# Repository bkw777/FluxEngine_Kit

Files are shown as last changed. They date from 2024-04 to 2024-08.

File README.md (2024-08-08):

# FluxEngine Kit

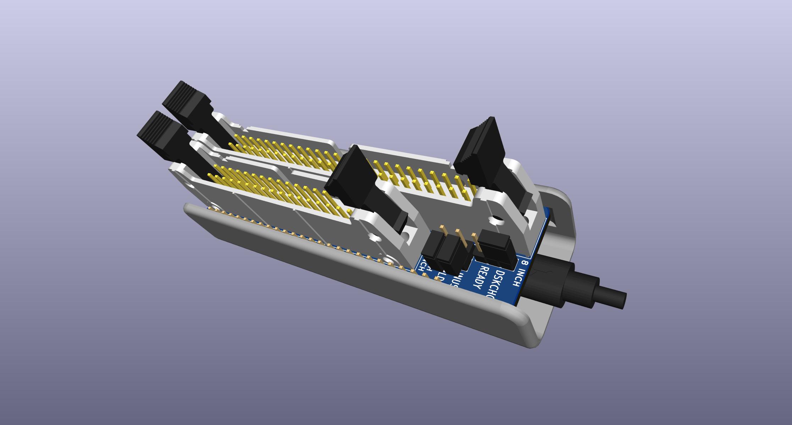
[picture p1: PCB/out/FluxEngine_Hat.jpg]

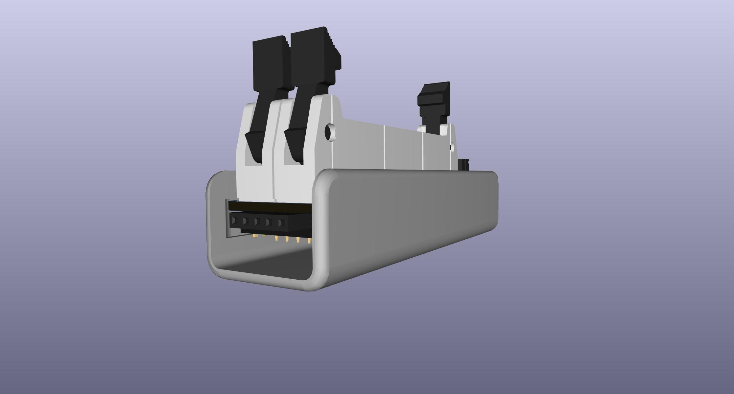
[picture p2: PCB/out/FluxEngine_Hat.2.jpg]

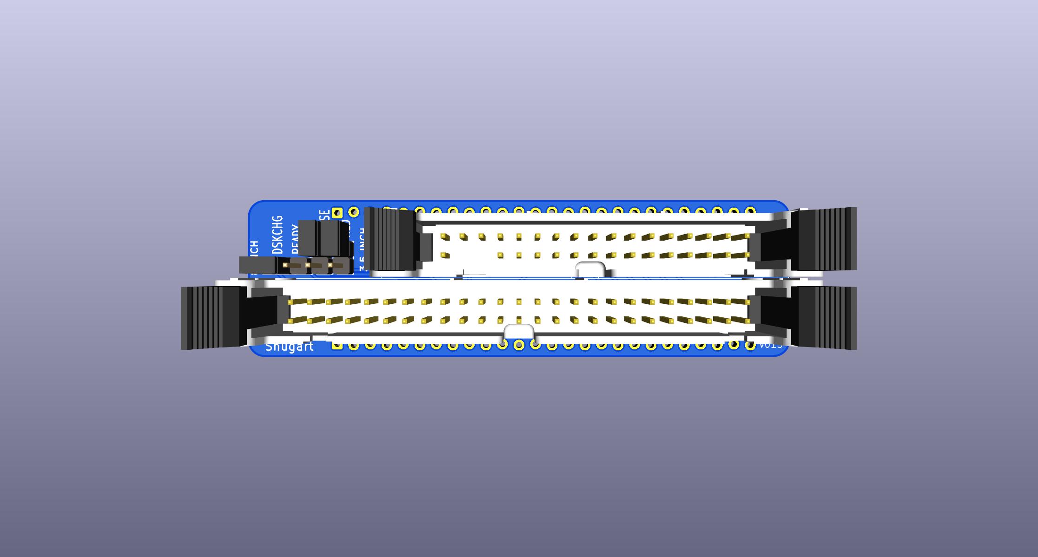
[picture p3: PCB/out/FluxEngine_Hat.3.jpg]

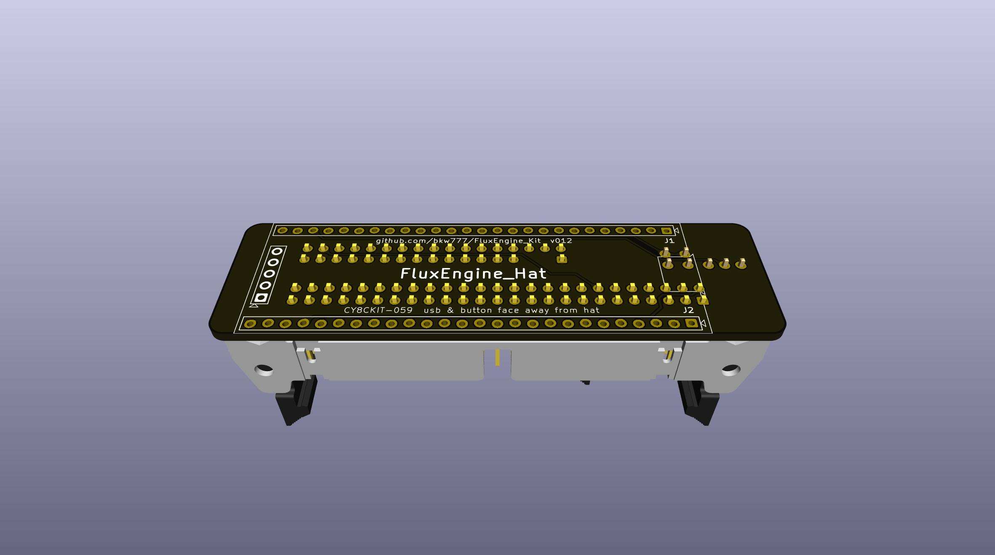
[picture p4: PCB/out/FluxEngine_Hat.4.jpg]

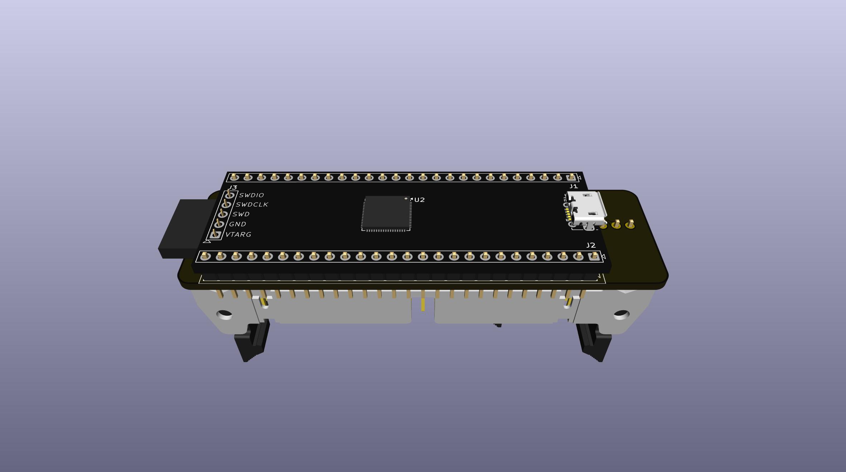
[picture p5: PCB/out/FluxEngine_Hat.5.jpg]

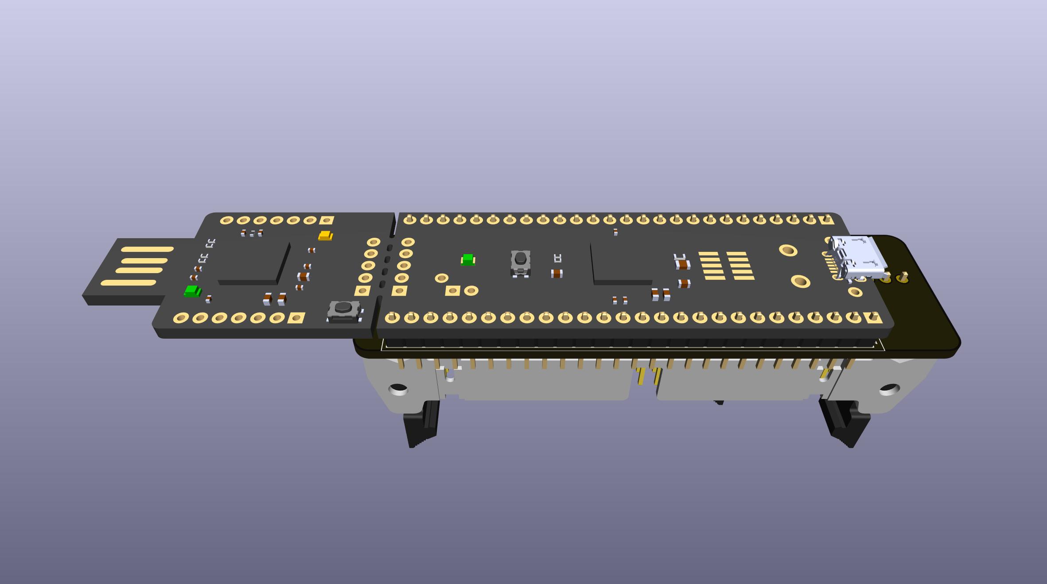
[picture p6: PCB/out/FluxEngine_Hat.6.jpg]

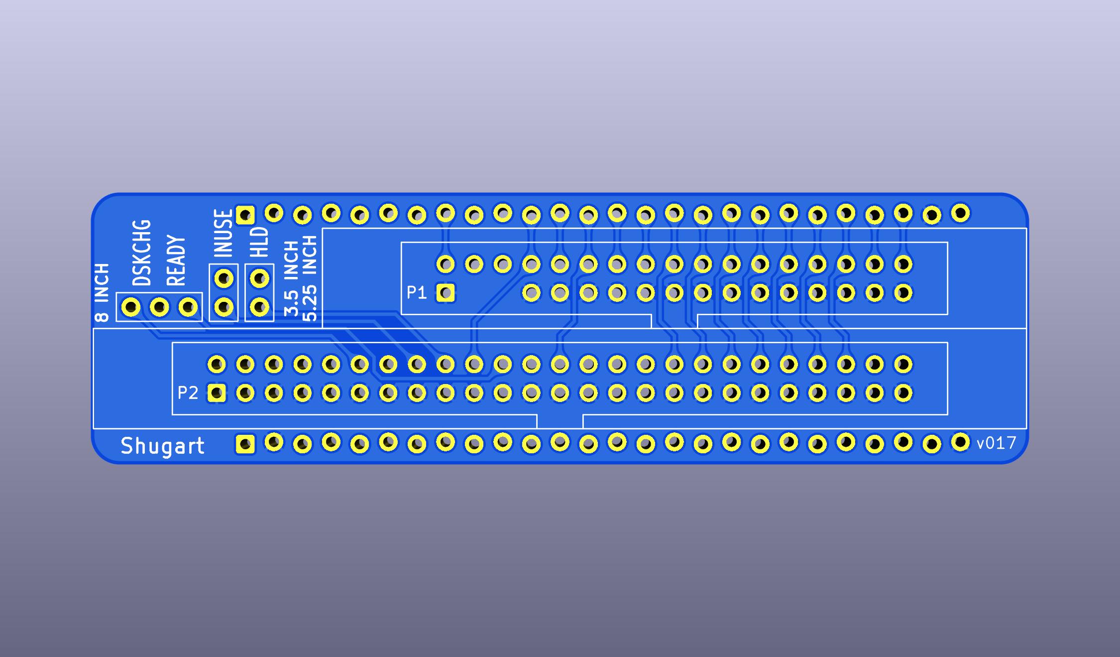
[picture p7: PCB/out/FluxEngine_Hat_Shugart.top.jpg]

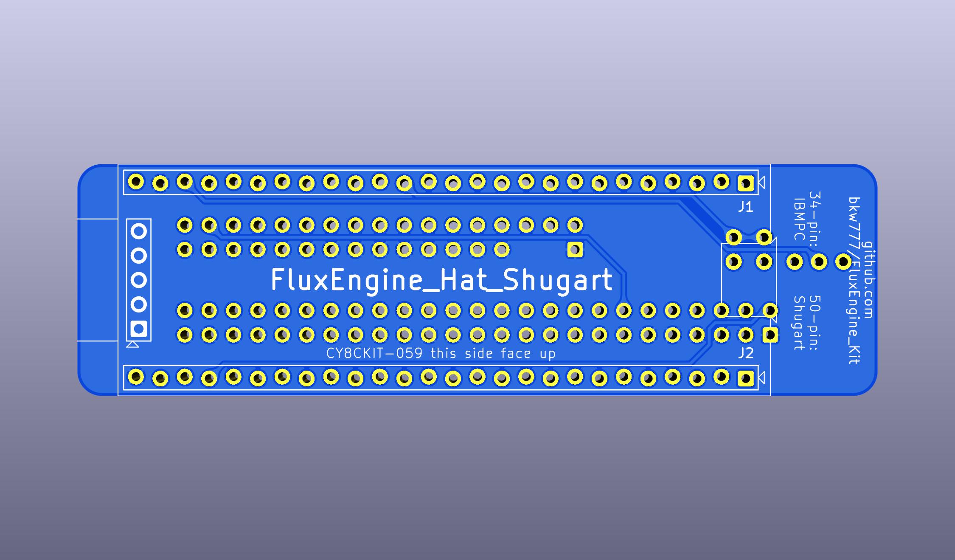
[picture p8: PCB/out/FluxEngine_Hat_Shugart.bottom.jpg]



THESE PCBs ARE NOT TESTED YET

This is a set of adapter PCBs and printable snap covers to build a nice version of [FluxEngine](http://cowlark.com/fluxengine/)

I am not the creator of FluxEngine itself, just this adapter PCB and printable cover.

Most people probably do not need any of these pcbs. They are really just to provide convenient support for 8-inch drives.

If you're not trying to use 8-inch drives, then you don't need any adapter pcb like this.  
The FluxEngine pinout is already designed so that you can just solder a 34-pin connector directly to the CY8CKIT-059 fpga board.  
You can use the BOM link below and delete everything but the CY8CKIT-059 and the 34-pin connector, no pcb, no printed cover.

The PCBs are designed to NOT need to be soldered. You can connect and remove and reconnect the fpga board without, and without needing to install actual sockets.
You CAN still solder them normally if you want to make a permanent FluxEngine, you just don't have to.

It means you can swap the same fpga board between all 3 (so far) hat versions, and then still also use the fpga board on a breadboard when not using it for FluxEngine.

What you do is solder pins to the bottom of the fpga board the same as if you were using it on a breadboard. And that's it. You can install actual matching sockets on the hat PCBs, but you don't have to. The zig/zag pin row layout on the hat PCBs makes solid electrical contact with the pins without needing a socket.

For the sake of the solderless pin connections, I suggest getting the PCBs made with ENIG finish (gold plating on the copper).  
It's not required though. Honestly the way the square edges of the pins bite into the via walls it probably will never make any difference.  
Some fabricators charge more than others for ENIG. OSHPark is always ENIG no matter what, so that's easy. But between PCBWAY, JLCPCB, and Elecrow, Elecrow charges a lot less for ENIG.

The cover (both styles) prints easily with any basic home FDM printer with PLA. I actually use a $150 Monoprice from 6 years ago.  

But also these days most of the PCB shops also offer 3d printing, so you can get the pcb and the cover printed professionally in sintered nylon from the same place on the same order.  
The link below is to PCBWAY only because it's the most convenient where you can just click "buy" on something already pre-loaded, but actually if you go to Elecrow and just upload the gerber zip and cover stl, it's just as simple and significantly cheaper, especially with ENIG.

## Parts
[BOM from DigiKey](https://www.digikey.com/short/q5zh79n9)  
[PCB and Cover from PCBWAY](https://www.pcbway.com/project/shareproject/FluxEngine_Hat_e3000eb5.html)

Power supply and cables:  
[Molex power supply](https://amazon.com/dp/B000MGG6SC)  
[Molex to Berg splitter](https://amazon.com/dp/B0002J1KW6)  
[Molex to Molex splitter](https://amazon.com/dp/B00007JO36)  
[Floppy drive cable](https://amazon.com/dp/B07KDJTMGP)  

## Cover

There are a few versions of printable cover in releases, all generated from the same OpenSCAD source.  
Two main styles, simple and fancy, in three sizes each, lowprofile, default, and one for if you have full pin sockets installed.  

## Configuration

The jumpers only affect the 50-pin connector for 8-inch drives.  

### DSKCHG / READY
Connects either the /DSKCHG or /READY output from the drive to the /DSKCHG input on the FluxEngine.  

Install jumper on DSKCHG by default.

### INUSE
Connects the /MOTB (motor-B-on) output from the FluxEngine to the /IN-USE aka /DOOR-LOCK input on the drive.

Not connected by default, but stow a jumper on one pin.

### HLD
Connects the /MOTB (motor-B-on) output from the FluxEngine to the /HEAD-LOAD input on the drive.

Not connected by default, but stow a jumper on one pin.

INUSE/HLD is not either-or. You may need either, or neither, or both.

# Control Data / Magnetic Peripherals / Honeywell 8-inch drives

Some CDC 8-inch drives like the 9404 and 9406-4 lines are Shugart compatible, and so for those just use the SA850 hat like any other Shugart interface drive.

Others have compatible signals but different pinouts.

The two tables below come from two CDC manuals covering many similar drive models spanning several years.  
Left: [CDC FDD FSM ('79)](PCB/datasheets/CDC_77834769_Y__FDD_FSM.pdf)  
Right: [CDC 9406 FSM ('82)](PCB/datasheets/CDC_77614903_AM__9406_FSM.pdf)  

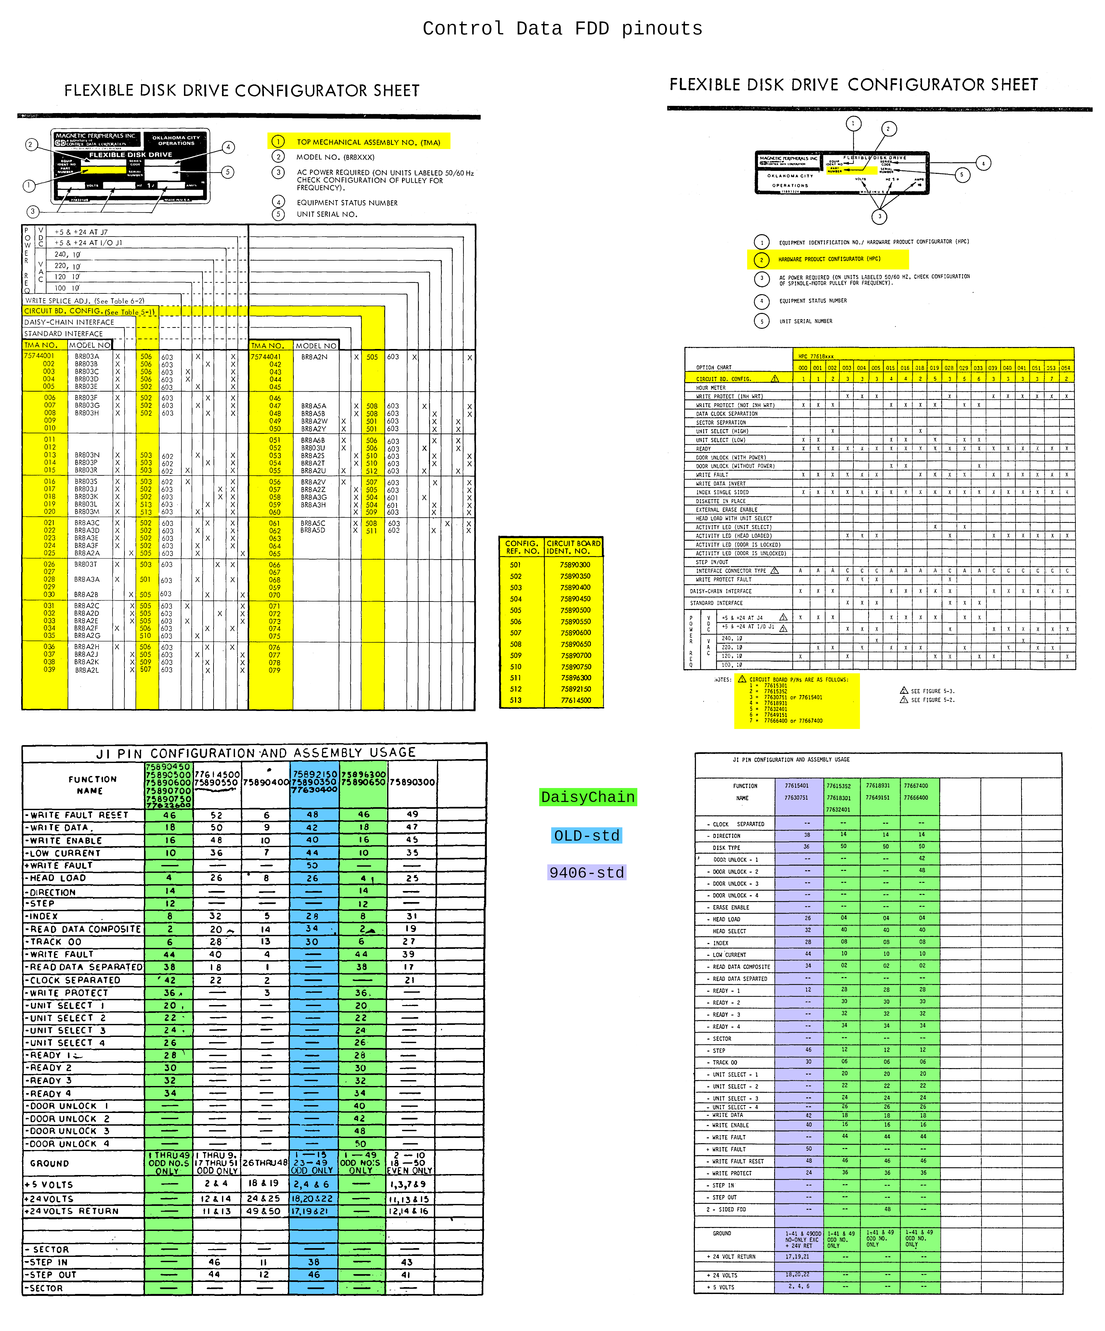
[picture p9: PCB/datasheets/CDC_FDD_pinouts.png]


There are two hats that cover the most common CDC pinouts.

The "CDC-daisychain" hat supports all the green highlighted models.

The "CDC-standard" hat supports the blue and purple highlighted models.

"standard" is mis-named because what CDC called "standard interface" in the manuals was several different pinouts and interfaces.  
But of the several pinouts they called "standard", 2 are actually the same except for STEP+DIRECTION vs STEP_IN/STEP_OUT, and most models that don't have the "daisychain" interface seem to have one of these two versions of "standard".  
So the '''CDC-standard''' hat includes logic to optionally convert the STEP+DIRECTION signals from the FluxEngine to STEP_IN/STEP_OUT signals for the drive if needed.

For drives that need STEP_IN/STEP_OUT, install the 2 jumpers on STEP_IN and STEP_OUT. (earlier and less common drives)  
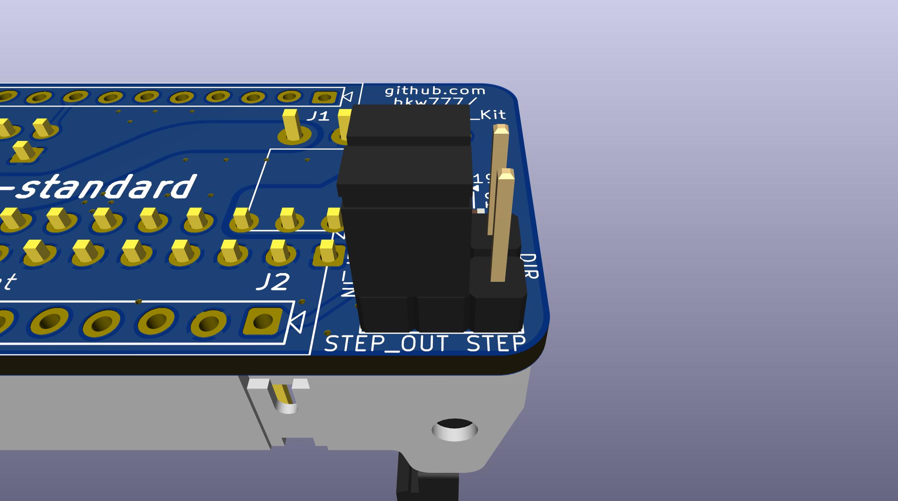
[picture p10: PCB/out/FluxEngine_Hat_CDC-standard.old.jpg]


For drives that need STEP+DIRECTION, install the 2 jumpers on DIR and STEP. (default, later and more common drives)  
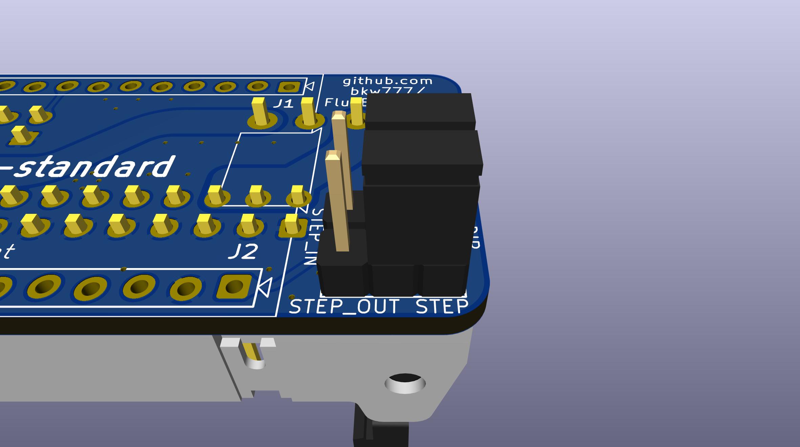
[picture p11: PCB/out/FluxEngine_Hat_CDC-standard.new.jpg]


If you don't need the STEP_IN/STEP_OUT option, you don't need to populate C1 or U1 or the jumper pins. Just use solder or wire in place of the STEP & DIR jumpers and leave the U1 and C1 footprints empty.  
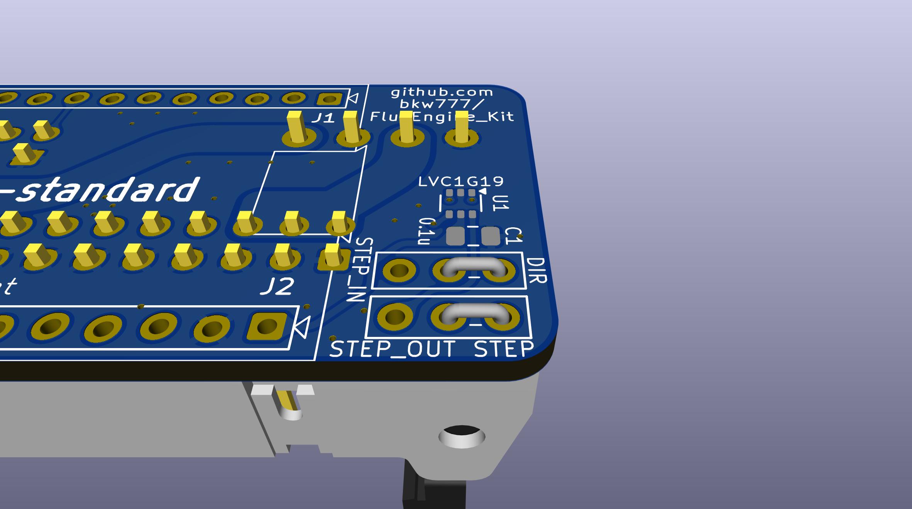
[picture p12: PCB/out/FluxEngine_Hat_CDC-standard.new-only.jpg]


NONE OF THESE ARE TESTED YET  


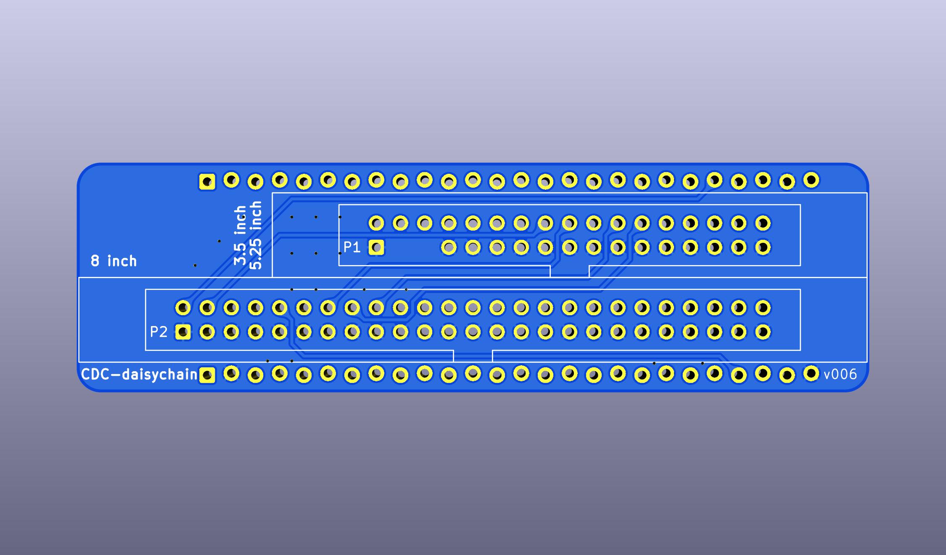
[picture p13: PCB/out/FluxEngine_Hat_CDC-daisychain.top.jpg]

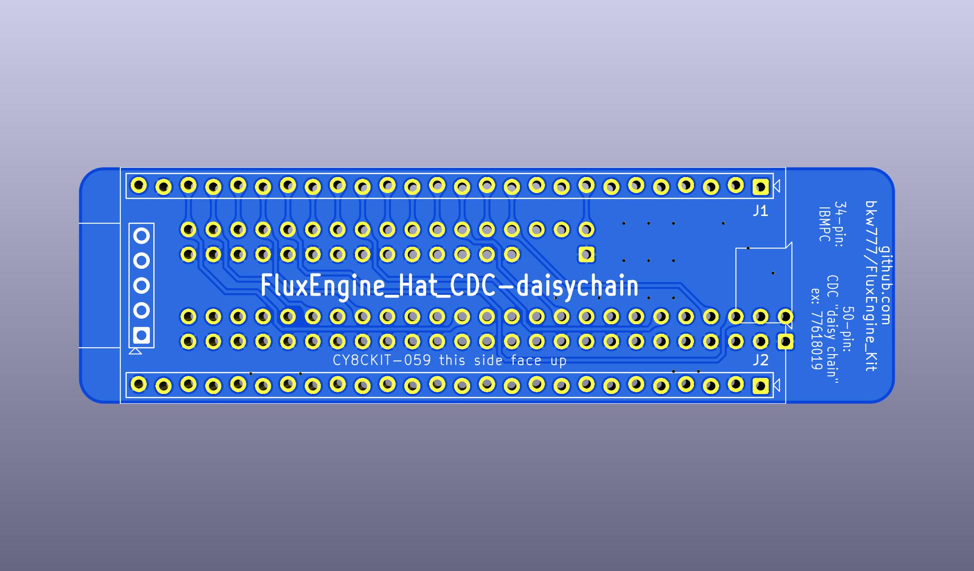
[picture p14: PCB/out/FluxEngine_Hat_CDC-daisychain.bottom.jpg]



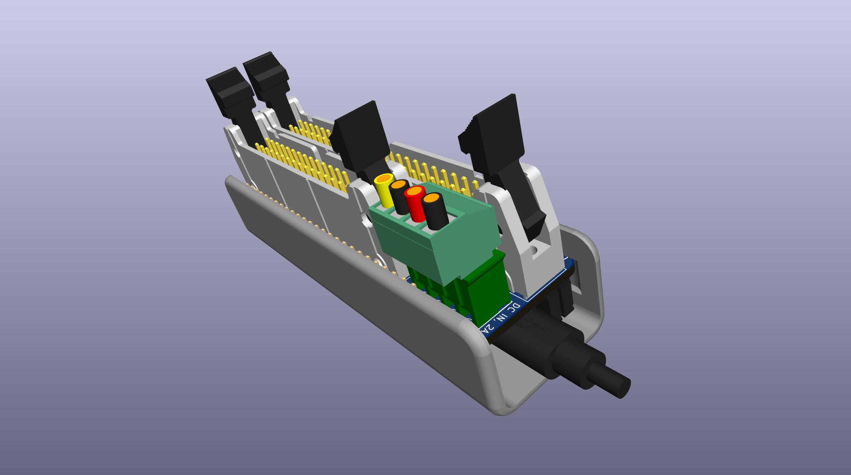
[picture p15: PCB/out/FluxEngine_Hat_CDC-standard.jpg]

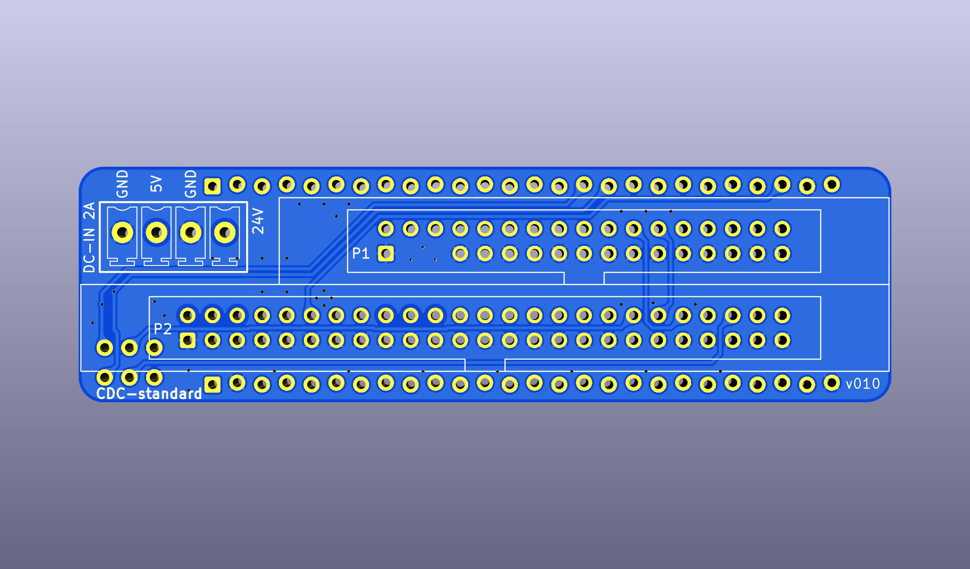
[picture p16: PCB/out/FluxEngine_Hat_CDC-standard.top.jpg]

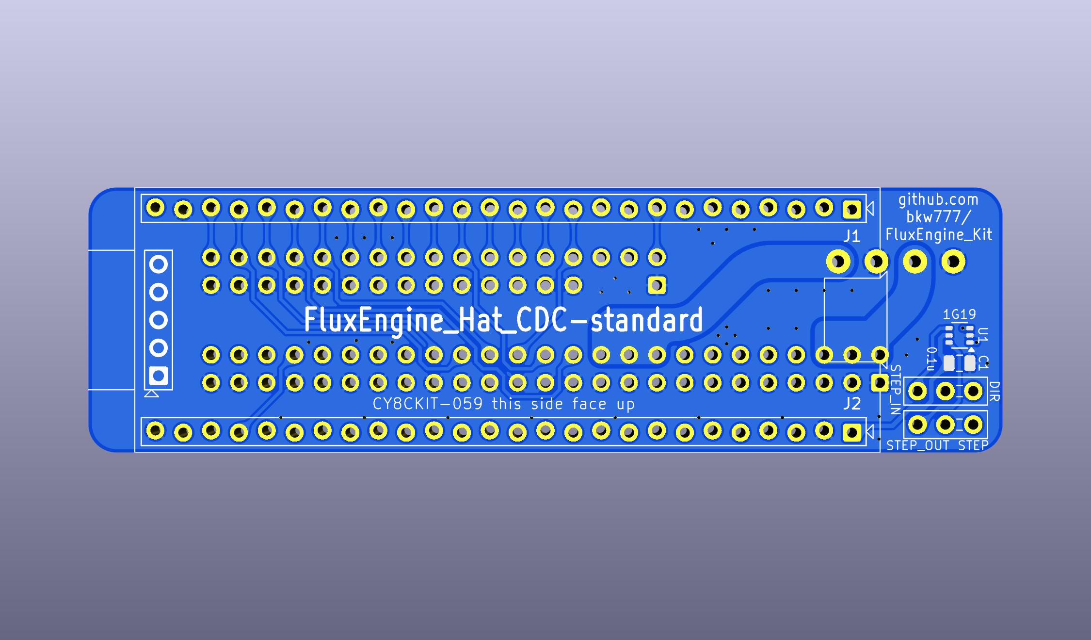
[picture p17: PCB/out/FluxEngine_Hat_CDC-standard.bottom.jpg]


CDC-daisychain BOM:  
Standard BOM, delete the jumpers.  

CDC-standard BOM:  
Standard BOM, add these:  
[screw terminal header](https://www.digikey.com/en/products/detail/phoenix-contact/5452094/5186805)  
[screw terminal plug](https://www.digikey.com/en/products/detail/phoenix-contact/5452178/5187210)  
[74LVC1G19 1to2 decoder](https://www.digikey.com/en/products/detail/nexperia-usa-inc/74LVC1G19GW-125/1231453)  
[C 0.1u 0805](https://www.digikey.com/en/products/detail/kyocera-avx/KGM21NR71E104KT/1116281)  

### More 8-inch info

The AC & DC power connectors were the same on many drives.  
These are the cable-side connector housings and female pins needed to make proper cables to connect to most drives.

3-pin AC power:  
Housing: [AMP/TE 1-480700-0](https://www.digikey.com/en/products/detail/te-connectivity-amp-connectors/1-480700-0/29339)  
Female pins: [AMP/TE 350536-1](https://www.digikey.com/en/products/detail/te-connectivity-amp-connectors/350536-1/287712)

6-pin DC power:  
Housing: [AMP/TE 1-480270-0](https://www.digikey.com/en/products/detail/te-connectivity-amp-connectors/1-480270-0/15668)  
Female pins: [AMP/TE 61117-1](https://www.digikey.com/en/products/detail/te-connectivity-amp-connectors/61117-1/290254)

They do make dual-output power supplies that output both 5v and 24v, but it's actually cheaper to buy seperate supplies.  
A typical drive draws about 1.0A-1.5A from either DC rail while working.  
Here are a couple of supplies just for convenience & reference:  
[5V 3A Meanwell](https://www.digikey.com/en/products/detail/mean-well-usa-inc/RS-15-5/7706168)  
[24V 3.2A Meanwell](https://www.digikey.com/en/products/detail/mean-well-usa-inc/RS-15-5/7706168)

### Probably CDC-specific

The CDC manuals do not say this anywhere, but many drives have a variant of the 50-pin IDC header with two polarity key slots instead of one in the center. The drawings and actual part numbers in the service manuals only show the normal single-notch type.  
A normal IDC plug with polarity key does not fit. Non-polarized plugs fit, but here are a couple of fully polarity-keyed female IDC plugs that fit:  
[Omron XG4M-5031-T](https://www.digikey.com/en/products/detail/omron-electronics-inc-emc-div/XG4M-5031-T/1829402)  
[Hirose HIF3BA-50D-2.54R](https://www.digikey.com/en/products/detail/hirose-electric-co-ltd/HIF3BA-50D-2-54R-63/12758574)

Connector housing & contacts to fit the 7-pin power connection on CDC drives.  
The pins are .156" pitch, and have a .031"x.062" flat blade shape not square.  
The pin and housing series is called "AMPMODU MOD I", and you want specifically the high pressure version of the receptacles for power vs merely signal usage.  
Only the 4 middle pins are connected, so you could uses as little as a 5-position housing, but ideally you still want a housing with all 7 (or more) positions, and receptacles installed for all 6 pins, because the extra 2 pins provide both strain relief and extra retention friction.  
[TE 87159-7 - AMPMODU MOD I receptacle housing, 7-pin, non-locking, keyed](https://mou.sr/4bhcBrf) (cut the key bumps off)  
[TE 102100-2 - AMPMODU MOD I pin receptacle, non-locking high-pressure 18-22awg gold-30uin](https://mou.sr/44tt5K6) (need 6)  
[TE 87116-2 - AMPMODU MOD I keying plug](https://us.rs-online.com/product/te-connectivity/87116-2/70287356/) (need 1)

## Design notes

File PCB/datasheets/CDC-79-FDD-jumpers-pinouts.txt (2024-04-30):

CDC FDD config jumpers for 8-inch models up to '79
from CDC_77834769_Y__FDD_FSM.pdf

Aside from looking at the schematic, trying to decode the config jumper table to
determine if there are config jumpers that correspond to STEP+DIR vs STEP_IN/STEP_OUT

Pinout groups (J1 config columns) 1 and 5 are the same except
group 5 adds DOOR_UNLOCK1-4 inputs and removes the SEP_DATA output.

Groups 2,3,4,6 are all the ones with STEP_IN/STEP_OUT at all, regardless of pinout.

Group 4 is the only one with all pins the the same as "ALT1"
(pinout group 1 from the later 9406 manual)
except for STEP_IN/STEP_OUT vs STEP+DIRECTION.

Some config changes involve installing different components
in a given footprint which changes functionality/behavior,
not just jumpers, but none of those are different for column 4.
(all the same ICs and values, at least in the stepper area)

Re-write of the jumper table with the related configs grouped together
-----------------------------------------------------------------------------
assembly  J1 cfg
number    column   installed W# locations
-----------------------------------------------------------------------------
                :  1 2 3 4 5 6 7 8 9 10 11 12 13 14 15 16 17 18 19 20 21 22 23 24 25 26 27 28 29 30 31 32 33 34 35 36 37 38
--------------------------------------------------------------------------------------------------------------------------
75890450    1   :    2   4     7              13    15 16             21 22       25    27    29    31                37
75890500    1   :    2   4     7           12 13 14 15                21 22       25    27    29    31             36 37
75890600    1   :    2   4     7              13 14 15                21 22    24       27    29    31                37
75890700    1   :    2     5   7              13 14 15             20       23 24       27    29    31             36 37
75890750    1   :    2   4     7              13 14 15                21 22       25    27    29    31             36 37
77622600    1   :    2   4     7              13 14 15    17          21 22       25    27    29    31             36 37
                :
75890650    5   :    2   4     7 8            13 14 15       18       21 22       25    27    29 31             35    37
75896300    5   :    2   4     7 8            13 14 15       18       21 22       25    27    29 31             35    37 
77624750(1) 5   :    2   4     7 8            13 14 15       18       21 22       25    27    29 31             35    37

75890550    2   :    2     5 6          11    13    15                21 22    24       27    29 31                   37
77614500    2   :    2     5 6          11    13    15                21 22    24       27    29 31                   37
75890300(2) 6   :    2     5 6          11    13    15                21 22    24       27    29 31                   37

75890400    3   :    2   4     7        11    13    15 16             21 22       25    27    29 31                   37

75890350    4   :  1 2     5   7        11    13    15                21 22    24          28 29 31                   37
75892150    4   :  1 2     5   7        11    13    15                21 22       25       28 29 31                   37
77630400    4   :  1 2     5   7        11    13 14 15                21 22    24             29 31                   37 38 

(1) 77624750 not listed in J1 table, assuming pinout 5 based on matching jumper set.

(2) Pinout 6 is the same as pinout 2 except J1 is a different physical connector,
    and all signals are swapped from the normal even row to the odd row. (Or maybe
    the signals are in the same physical locations, and the pins are just called by
    the "wrong" numbers. The drawing on page 5-10 looks like that.)

There seem to be inconsistencies in the effects of some jumpers.
IE, W7 seems to mean STEP_IN/OUT in group 4,
yet all of group 5 also has W7 yet has STEP+DIR not STEP_IN/OUT.

The different PCB numbers must have at least some different trace artwork
just to produce the different physical connectors and pinouts from the same
schematic and component footprint layout. So probably a given jumper location
location like W7 just has different functions on the different PCB numbers.

What does seem to be consistent is the effect of a given jumper location within a pinout group.

Function of ALL config jumpers
account for them all to know if there are any besides W6 & W7
that may possibly affect STEP+DIRECTION
--------------------------------------------------------------------
Jumper Schem.  
  W#   Sheet#  Description or at least related function
--------------------------------------------------------------------
   1     5     write-fault +
   2     2     write data - ?
   3     2     write data + ?
   4     3     wprot inhibits write
   5     3     wprot does not inhibit write
   6     3     STEP DIRECTION
   7     3     STEP DIRECTION
   8     4     door unlock 1-4 pullup
   9     4     door unlock 1-4 pulldown
  10     5     trk0
  11     4     unit always selected without unit select input
  12     5     ignore head load, head loaded with unit select
  13     5     trk0
  14     4     index/ready
  15     4     index/ready
  16     4     index/ready
  17     4     unit select -> door unlock
  18     4     door unlock 1-4 -> door unlock
  19     4     head load -> door unlock
  20     4     unit select -
  21     4     unit select
  22     4     unit select +
  23     4     unit select
  24     3     no power reduction option
  25     3     power reduction option
  26     5     trk0
  27     4     door closed -> ready
  28     4     unit select -> ready
  29     5     trk0 N.C.
  30     5     trk0
  31     5     trk0 N.O 
  32     4     door unlock 1-4
  33     4     ready 1-4
  34     4     unit select 1-4
  36     3     sep clock
  37     4     sector/index detector
  38     4     index/ready

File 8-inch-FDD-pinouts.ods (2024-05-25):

PIN | SA850/851 | YD-174 | M2896-63 | TM848-2 | CDC_9406(1) | CDC_9406(2,3,4) | CDC_FDD(1) | CDC_FDD(5)
2 | TG43 | TG43 | TG43 | TG43 | 5VDC | RDATA | RDATA | RDATA
4 |  |  |  |  | 5VDC | HLD | HLD | HLD
6 |  |  |  | MOTOR_OFF | 5VDC | TRK0 | TRK0 | TRK0
8 |  |  | TRUE_READY |  |  | INDEX | INDEX | INDEX
10 | FD2S | FD2S | FD2S | FD2S |  | TG43 | TG43 | TG43
12 | DSKCHG | DSKCHG | DSKCHG | DSKCHG | READY | STEP | STEP | STEP
14 | SIDE | SIDE | SIDE | SIDE |  | DIR | DIR | DIR
16 | INUSE | INUSE | INUSE | INUSE |  | WGATE | WGATE | WGATE
18 | HLD | HLD | HLD |  | 24VDC | WDATA | WDATA | WDATA
20 | INDEX | INDEX | INDEX | INDEX | 24VDC | DS1 | DS1 | DS1
22 | READY | READY | READY | READY | 24VDC | DS2 | DS2 | DS2
24 | SECTOR |  |  |  | WPROT | DS3 | DS3 | DS3
26 | DS1 | DS1 | DS1 | DS1 | HLD | DS4 | DS4 | DS4
28 | DS2 | DS2 | DS2 | DS2 | INDEX | READY1 | READY1 | READY1
30 | DS3 | DS3 | DS3 | DS3 | TRK0 | READY2 | READY2 | READY2
32 | DS4 | DS4 | DS4 | DS4 | SIDE | READY3 | READY3 | READY3
34 | DIR | DIR | DIR | DIR | RDATA | READY4 | READY4 | READY4
36 | STEP | STEP | STEP | STEP | FD2S | WPROT | WPROT | WPROT
38 | WDATA | WDATA | WDATA | WDATA | DIR |  | SEPDATA | SEPDATA
40 | WGATE | WGATE | WGATE | WGATE | WGATE | SIDE |  | DUNLOCK1
42 | TRK0 | TRK0 | TRK0 | TRK0 | WDATA | (UNLOCK1) | SEPCLOCK | DUNLOCK2
44 | WPROT | WPROT | WPROT | WPROT | TG43 | WFAULT | WFAULT | WFAULT
46 | RDATA | RDATA | RDATA | RDATA | STEP | WF_RESET | WF_RESET | WF_RESET
48 | SEPDATA |  |  |  | WF_RESET | (2SFDD) |  | DUNLOCK3
50 | SEPCLOCK |  |  |  | WFAULT+ | FD2S |  | DUNLOCK4

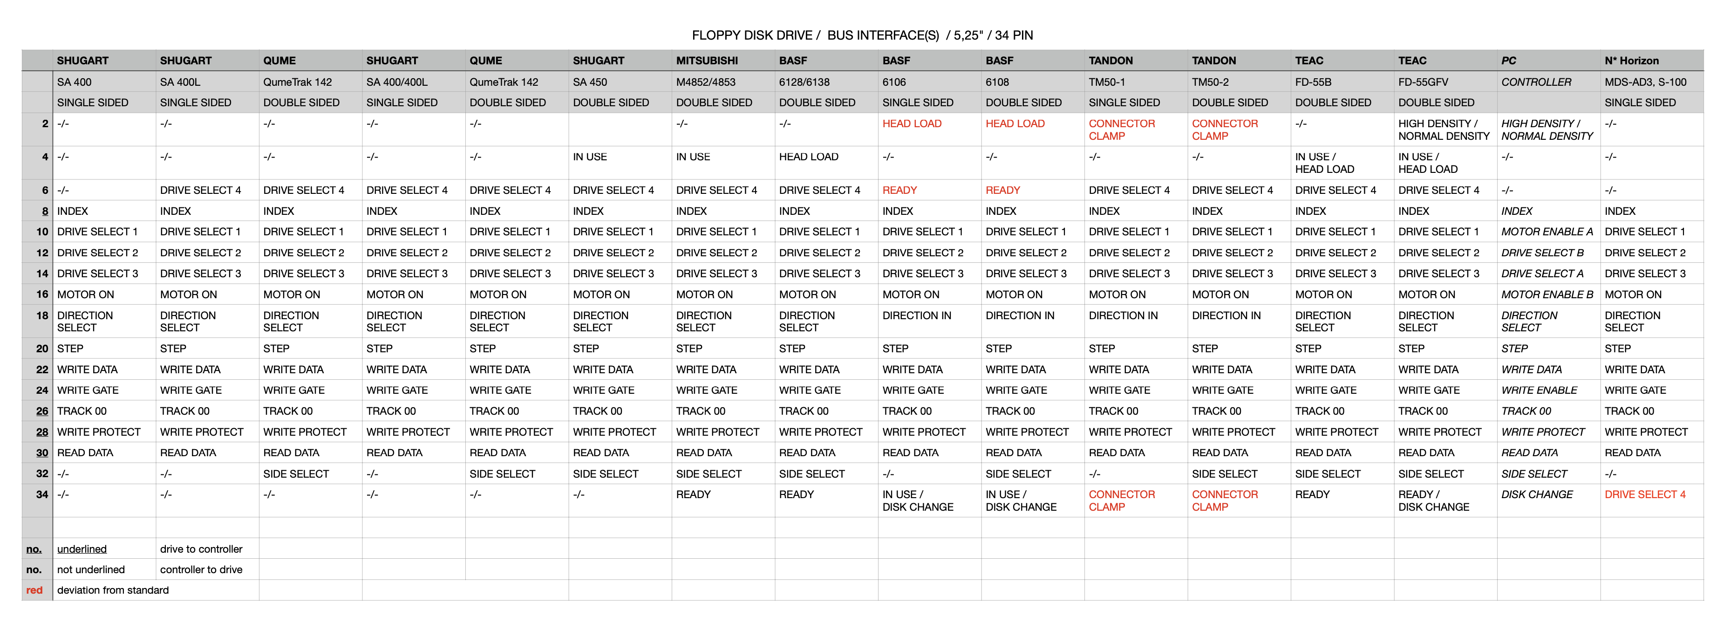
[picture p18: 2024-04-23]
PCB/datasheets/fdd-bus-interface-34p_5.25inch.png

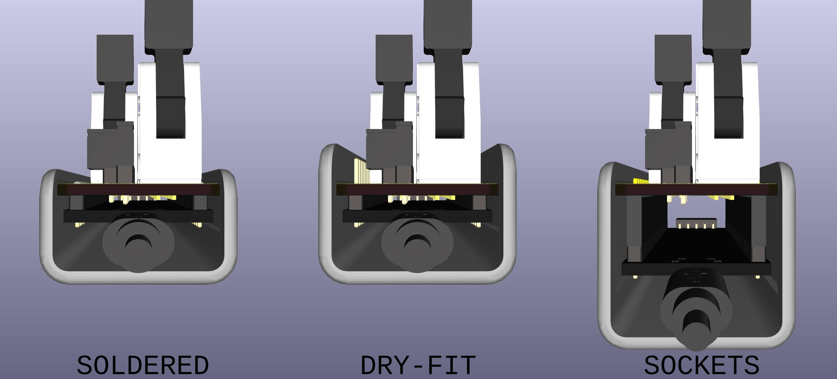
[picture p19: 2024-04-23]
PCB/out/SimpleCover_styles.jpg

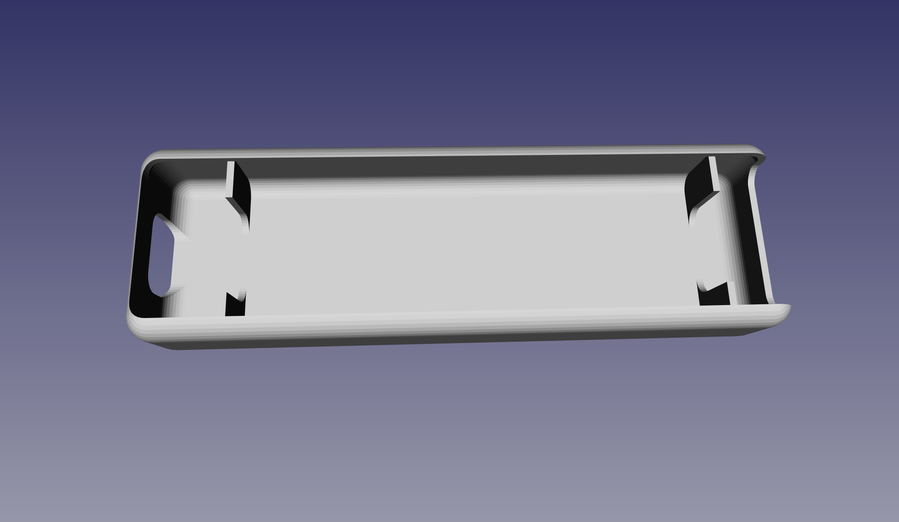
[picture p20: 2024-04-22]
CASE/out/FancyCover.jpg

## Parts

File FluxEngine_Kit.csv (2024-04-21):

Index | Quantity | Part Number | Manufacturer Part Number | Description | Customer Reference | Available | Backorder | Unit Price | Extended Price USD
1 | 1 | 448-CY8CKIT-059-ND | CY8CKIT-059 | CY8C58LP EVAL BRD |  | 1 | 0 | 20.90000 | 20.90
2 | 1 | 1568-1512-ND | PRT-12795 | JUMPER WIRE M/M 6" 20PCS |  | 1 | 0 | 2.10000 | 2.10
3 | 1 | 609-6212-ND | 86130342114345E1LF | CONN HEADER VERT 34POS 2.54MM |  | 1 | 0 | 1.37000 | 1.37
4 | 1 | 609-6244-ND | 86130502114345E1LF | CONN HEADER VERT 50POS 2.54MM |  | 1 | 0 | 1.70000 | 1.70
5 | 2 | S5480-ND | PPPC051LGBN-RC | CONN HDR 5POS 0.1 GOLD PCB R/A |  | 2 | 0 | 0.67000 | 1.34
6 | 3 | S9001-ND | SPC02SYAN | CONN JUMPER SHORTING GOLD FLASH |  | 3 | 0 | 0.10000 | 0.30
7 | 2 | S1011EC-40-ND | PRPC040SAAN-RC | CONN HEADER VERT 40POS 2.54MM | PINS | 2 | 0 | 0.67000 | 1.34

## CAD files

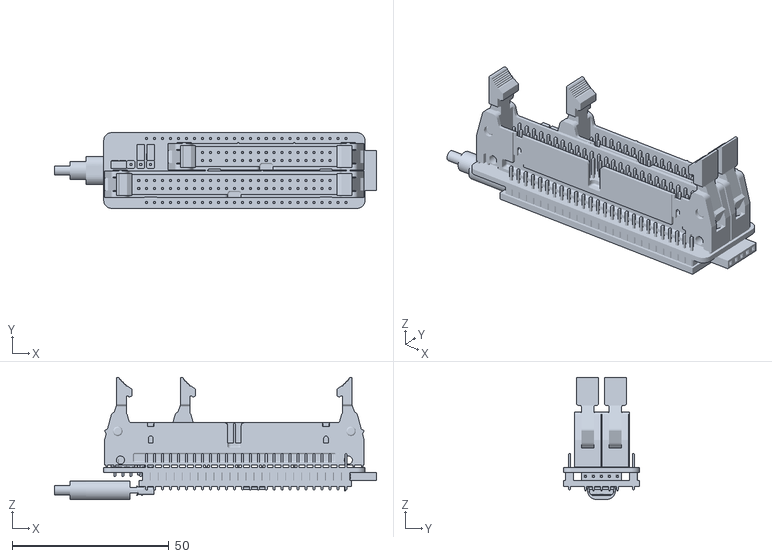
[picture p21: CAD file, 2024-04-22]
CASE/PCBs.stl
102.6 x 24.1 x 39.0

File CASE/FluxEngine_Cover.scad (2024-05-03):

/*
   Fancy Cover for FluxEngine_Hat
   Brian K. White - b.kenyon.w@gmail.com
   https://github.com/bkw777/FluxEngine_Kit
   v014
*/

// ===== OPTIONS ===============================================

style = "simple";   // "fancy" "simple"
lowprofile = false;
sockets = false;

// for the lowprofile simple cover,
// leave a thin wall over the usb plug
lpx = false;

orient_render_for_printing = false;

// =============================================================

pcb_stl =
        (sockets) ? "PCBs_sockets.stl" :
        "PCBs.stl";

$fn = 36;         // arc smoothness

wt = (style=="fancy") ? 1 : 2; // wall thickness
fc = 0.4;         // fitment clearance
o = 0.1;          // overcut/overlap/overextend
r = 2.54;         // inside radii, 0.001 to (fc+usb_plug_h+fc)/2

pcb_w = 83.312;   // hat pcb long dim
pcb_d = 24.13;    // hat pcb short dim
pcb_h = 1.6;      // pcb thickness
pcb_t = r/2;      // hat pcb top surface to ceiling

fpga_xlen = 67.894; // fpga pcb long dim
fpga_xpos = 3.5;  // fpga pcb center x-axis offset from hat pcb
fpga_pcb_h = 2;   // fpga pcb thickness (it's not 1.6)

el = (style=="fancy") ? 2.5 : 4; // extend shell to protect programmer socket

rl = 1.27;        // top retaining lip overhang

sockets_height = (sockets) ? 8.5 : 0; // sockets add 8.5mm height between pcbs
pin_ins_h = 2.54 + sockets_height; // pin header insulator height
usb_plug_h = 7;   // usb cable plug thickness
usb_plug_d = 11;  // usb cable plug width
usb_jack_h = 2.6; // usb jack thickness, not counting funnel
prog_h = 2.54;    // programmer socket thickness
prog_d = 5*2.54;  // programmer socket long dim
prog_c = fc ; //fc; // clearance around programmer socket

tih = pcb_t + pcb_h; // top interior height

// bottom interior height
bih =
        (lowprofile) ? pin_ins_h + fpga_pcb_h + usb_jack_h + fc :
        pin_ins_h + fpga_pcb_h + usb_jack_h/2 + usb_plug_h/2 + fc ;

beh = bih + fc + wt; // bottom exterior height
ih = tih + bih;      // total interior height
iw = fc+pcb_w+fc+el; // interior cavity long dim
id = fc+pcb_d+fc;    // interior cavity short dim

post_w = wt;         // support posts thickness

mwt = 0.8;           // min wall thickness
ew = el + pcb_w + el; // exterior width (length really, the long dim)
ed = mwt + fc + pcb_d + fc + mwt; // exterior depth (width really, the short horiz dim)
exposed_pins_height = (lowprofile) ? 2 : 5;
assert(exposed_pins_height>1);
teh = (style=="fancy") ? tih + wt : pcb_h + exposed_pins_height; // top exterior height
eh = teh + beh; // exterior height
irmaj = 2;
rmaj = irmaj+wt;
rmin = wt;

// =============================================================

include <handy.scad>;

%import(pcb_stl);



///////////////////////////////////////////////////////////////
// SIMPLE
///////////////////////////////////////////////////////////////

module simple_cover () {

  difference() {
  
    // add
    hull() {
      // top
      mirror_copy([0,1,0])
        translate([0,ed/2-wt,-rmaj+teh])
          rotate([90,0,0])
            rounded_cube(w=ew,d=rmaj*2,h=wt*2,rh=rmaj,rv=rmin,t=0);
      // bottom
      mirror_copy([1,0,0])
        translate([ew/2-wt,0,rmaj-beh])
          rotate([0,90,0])
            rounded_cube(w=rmaj*2,d=ed,h=wt*2,rh=rmaj,rv=rmin,t=0);
    }
  
    // remove
    union() {
      translate([0,0,eh/2-beh+wt])
        rotate([90,0,90])
          D(h=o+ew+o,d=eh,w=ed-wt*2,r=irmaj);

      ch = fc+pcb_h+pin_ins_h+fpga_pcb_h+fc;
      hull() {
        mirror_copy([1,0,0])
          translate([pcb_w/2-r+fc,0,0])
            mirror_copy([0,1,0])
              translate([0,pcb_d/2-r,-ch/2+pcb_h+fc])
                cylinder(h=ch,r=r+fc,center=true);
      }
      
      if (lowprofile) {
        ucw = 20;
        if (lpx) {
          translate([fpga_xpos-ucw/2-fpga_xlen/2,0,-beh+wt/2+mwt])
            rotate([90,0,90])
              D(d=wt,h=ucw,w=1+usb_plug_d+1,r=r);
        } else {
          translate([fpga_xpos-ucw/2-fpga_xlen/2,0,-beh+wt/2])
            rotate([0,0,90])
              D(h=o+wt+o,d=ucw,w=1+usb_plug_d+1,r=r);
        }
      }
    
    }
  
  }


}



///////////////////////////////////////////////////////////////
// FANCY
///////////////////////////////////////////////////////////////

module fancy_cover () {
  union() {
  
    difference() {
  
      // main body shell
      translate([el/2,0,-ih/2+tih])
        rounded_cube(w=iw,d=id,h=ih,rh=r,rv=r,t=wt);
  
      // cutouts
      union() {
        cw = 20;
        ch = ih*2;
        // main top cutout
        translate([el/2+r+wt,0,ch/2-prog_h-prog_c-sockets_height])
          rounded_cube(w=iw+r*2+wt*2,d=pcb_d-rl*2,h=ch,rh=r,rv=r,t=0);
        // usb port
        translate([-cw/2-fpga_xlen/2+fpga_xpos,0,-pin_ins_h-fpga_pcb_h-usb_jack_h/2])
          rounded_cube(w=cw,d=fc+usb_plug_d+fc,h=fc+usb_plug_h+fc,rh=r,rv=r,t=0);
      }
  
    }
  
    // support & registration posts
    translate([fpga_xpos,0,-fc]) {
      mirror_copy([1,0,0]) {
        translate([fpga_xlen/2+post_w/2+fc,0,0]) {
  
          // lowprofile version needs the fillets reduced
          // to stay out of the usb opening
          ec = (lowprofile) ? wt*0.75 : 0;
  
          difference () {
            translate([0,0,-bih/2])
              rotate([90,0,90])
                D(w=o+id+o,d=bih,h=post_w,r=r);
            translate([0,0,-bih/2+fc-ec/2])
              rotate([90,0,90])
                D(w=prog_d+prog_c*2,d=bih+ec,h=o+post_w+o,r=r);
          }
  
        }
  
      }
    }
  }
}



///////////////////////////////////////////////////////////////
// RENDER
///////////////////////////////////////////////////////////////

  if (style=="fancy") {
    pz = (orient_render_for_printing && !$preview) ? beh : 0;
    translate ([0,0,pz])
      fancy_cover();
  } else {
    pr = (orient_render_for_printing && !$preview) ? 90 : 0;
    pz = (orient_render_for_printing && !$preview) ? ew/2 : 0;
    px = (orient_render_for_printing && !$preview) ? beh-eh/2 : 0;    
    translate ([px,0,pz])
      rotate([0,pr,0])
        simple_cover();
  }

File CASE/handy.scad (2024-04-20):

// b.kenyon.w@gmail.com - handy box
// fillets and handy things made from fillets

/*
   screw_post(h=10,od=6,id=3,fr=2,ch=0,o=0)

     cylindrical screw post with filleted base

     h = height
     od = main cylinder OD
     id = screw hole ID - default no hole
     fr = base fillet radius
     ch = screw hole chamfer depth - default no chamfer
     o = fillet ID shrink offset - usually unset

   rounded_cube(w=60,d=40,h=20,rh=2,rv=1,t=0)

     cube with rounded corners, optionally hollow

     w = width
     d = depth
     h = height
     rh = horizontal radius
     rv = vertical radius
     t = wall thickness - if set, makes a hollow box

   fillet_polar(o=false,R=1,r=1,A=90,a=90,as=0)

     creates both internal and external radial fillets
     used to create screw_post() and rounded_cube()
  
     o = outside true/false - default false (inside/concave)
     R = big radius
     r = small radius
     A = big angle
     a = small angle
     as = small angle start angle

   fillet_linear(o=false,l=1,r=1,a=90)
   
     o = outside - true/false - default false (inside/concave)
     l = length
     r = radius
     a = angle

*/

//$fs = 0.5;
//$fa = 1;
//$fn = 96;
//$fn = 72;
//$fn = 36;
//$fn = 12;

// examples:
//translate([60,0,0]) screw_post(h=10,od=6,id=3,fr=2,ch=0.6);
//difference() { rounded_cube(w=70,d=55,h=25,rh=3,rv=1,t=2); translate([0,-40,0]) cube([40,40,20]); }
//difference() { rounded_cube(w=70,d=55,h=25,rh=3,rv=1); translate([0,-40,0]) cube([40,40,20]); }
//fillet_linear(l=40);
//fillet_polar(R=2,r=1);

module screw_post(h=10,od=6,id=0,fr=2,o=0,ch=0) {
 x = (o) ? o : ($fn>=3) ? 0 : 0.025;
 difference() {
  union(){
   translate([0,0,h/2]) cylinder(h=h,d=od,center=true);
   translate([0,0,fr+x]) fillet_polar(R=-od/2+x,r=fr+x,A=360,as=90);
  }
  if(id>0) {
   translate([0,0,h/2]) cylinder(h=h+0.1,d=id,center=true);
   if(ch) translate([0,0,h-id/2-ch]) cylinder(h=od/2,d1=0,d2=od);
  }
 }
}

module rounded_cube(w=60,d=40,h=20,rh=2,rv=1,t=0) {
  if(t) difference() {
   _hbrc(w=t+w+t,d=t+d+t,h=t+h+t,rh=rh+t,rv=rv+t);
   _hbrc(w=w,d=d,h=h,rh=rh,rv=rv);
  }
  else _hbrc(w=w,d=d,h=h,rh=rh,rv=rv);
}

module _hbrc(w=60,d=40,h=20,rh=2,rv=1) {
 hull() {
  mirror_copy([0,0,1])
   mirror_copy([0,1,0])
    mirror_copy([1,0,0])
     translate([w/2-rh,d/2-rh,h/2-rv])
      fillet_polar(o=true,R=rh,r=rv);
 }
}

module fillet_polar(o=false,R=1,r=1,A=90,a=90,as=0) {
 rotate_extrude(angle=A)
  translate([R-r,0,0])
   rotate([0,0,-as])
    _hbf(o,r,a);
}

module fillet_linear(o=false,l=1,r=1,a=90) {
 linear_extrude(height=l,center=false)
  _hbf(o,r,a);
}

// D or bathtub shaped cube with 2 corners rounded
module D (w=10,d=10,h=1,r=2) {
  hull() {
   translate([0,r/2,0])
    cube([w,d-r,h],center=true);
   mirror_copy([1,0,0])
    translate([w/2-r,-d/2+r,0])
     cylinder(h=h,r=r,center=true);
  }
}

module _hbf(o=false,r=1,a=90) { // 2d fillet
 if(o) intersection() { circle(r=r); _hbw(r=r,a=a); }
 else difference() { _hbw(r=r,a=a); circle(r=r); }
}

module _hbw (r=1,a=90) { // 2d wedge polygon
  polygon([ [0,0], [0,r], [r*tan(a/2),r], [r*sin(a),r*cos(a)] ]);
}

module mirror_copy(v) {
 children();
 mirror(v) children();
}

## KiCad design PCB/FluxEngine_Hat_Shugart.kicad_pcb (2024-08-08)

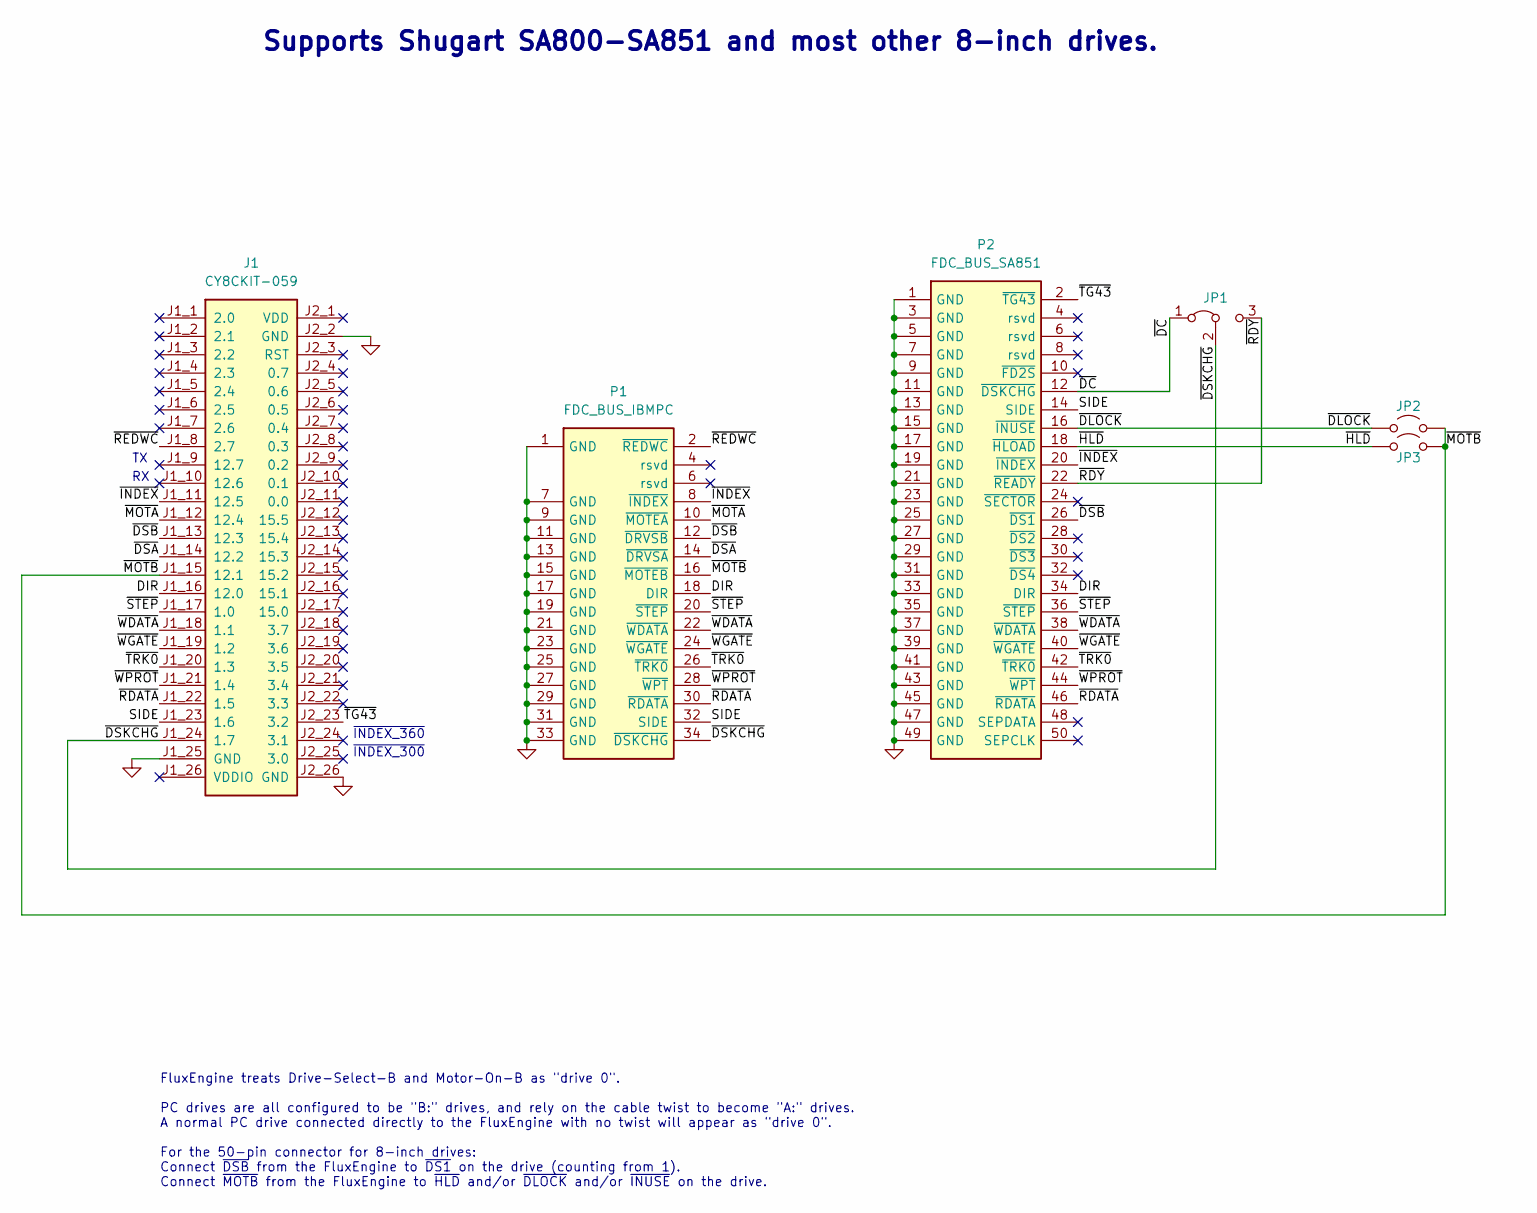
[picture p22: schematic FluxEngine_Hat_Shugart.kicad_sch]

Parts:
J1: CY8CKIT-059; CY8CKIT-059 dry fit
JP1: Jumper_3_Bridged12; PinHeader_1x03_P2.54mm_Vertical
JP2, JP3: Jumper_2_Open; PinHeader_1x02_P2.54mm_Vertical
P1: FDC_BUS_IBMPC; IDC-Header_2x17_P2.54mm_Latch_Vertical - FDD
P2: FDC_BUS_SA851; IDC-Header_2x25_P2.54mm_Latch_Vertical

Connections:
/DIR: J1.J1_16 (12.0), P1.18 (DIR), P2.34 (DIR)
/SIDE: J1.J1_23 (1.6), P1.32 (SIDE), P2.14 (SIDE)
/~DC: JP1.1 (A), P2.12 (~DSKCHG)
/~DLOCK: JP2.1 (A), P2.16 (~INUSE)
/~DSA: J1.J1_14 (12.2), P1.14 (~DRVSA)
/~DSB: J1.J1_13 (12.3), P1.12 (~DRVSB), P2.26 (~DS1)
/~DSKCHG: J1.J1_24 (1.7), JP1.2 (C), P1.34 (~DSKCHG)
/~HLD: JP3.1 (A), P2.18 (~HLOAD)
/~INDEX: J1.J1_11 (12.5), P1.8 (~INDEX), P2.20 (~INDEX)
/~MOTA: J1.J1_12 (12.4), P1.10 (~MOTEA)
/~MOTB: J1.J1_15 (12.1), JP2.2 (B), JP3.2 (B), P1.16 (~MOTEB)
/~RDATA: J1.J1_22 (1.5), P1.30 (~RDATA), P2.46 (~RDATA)
/~RDY: JP1.3 (B), P2.22 (~READY)
/~REDWC: J1.J1_8 (2.7), P1.2 (~REDWC)
/~STEP: J1.J1_17 (1.0), P1.20 (~STEP), P2.36 (~STEP)
/~TG43: J1.J2_23 (3.2), P2.2 (~TG43)
/~TRK0: J1.J1_20 (1.3), P1.26 (~TRK0), P2.42 (~TRK0)
/~WDATA: J1.J1_18 (1.1), P1.22 (~WDATA), P2.38 (~WDATA)
/~WGATE: J1.J1_19 (1.2), P1.24 (~WGATE), P2.40 (~WGATE)
/~WPROT: J1.J1_21 (1.4), P1.28 (~WPT), P2.44 (~WPT)
GND: J1.J1_25 (GND), J1.J2_2 (GND), J1.J2_26 (GND), P1.1 (GND), P1.7 (GND), P1.9 (GND), P1.11 (GND), P1.13 (GND), P1.15 (GND), P1.17 (GND), P1.19 (GND), P1.21 (GND), P1.23 (GND), P1.25 (GND), P1.27 (GND), P1.29 (GND), P1.31 (GND), P1.33 (GND), P2.1 (GND), P2.3 (GND), P2.5 (GND), P2.7 (GND), P2.9 (GND), P2.11 (GND), P2.13 (GND), P2.15 (GND), P2.17 (GND), P2.19 (GND), P2.21 (GND), P2.23 (GND), P2.25 (GND), P2.27 (GND), P2.29 (GND), P2.31 (GND), P2.33 (GND), P2.35 (GND), P2.37 (GND), P2.39 (GND), P2.41 (GND), P2.43 (GND), P2.45 (GND), P2.47 (GND), P2.49 (GND)

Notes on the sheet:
~{INDEX_300}
FluxEngine treats Drive-Select-B and Motor-On-B as "drive 0". PC drives are all configured to be "B:" drives, and rely on the cable twist to become "A:" drives. A normal PC drive connected directly to the FluxEngine with no twist will appear as "drive 0". For the 50-pin connector for 8-inch drives: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
Supports Shugart SA800-SA851 and most other 8-inch drives.
~{INDEX_360}

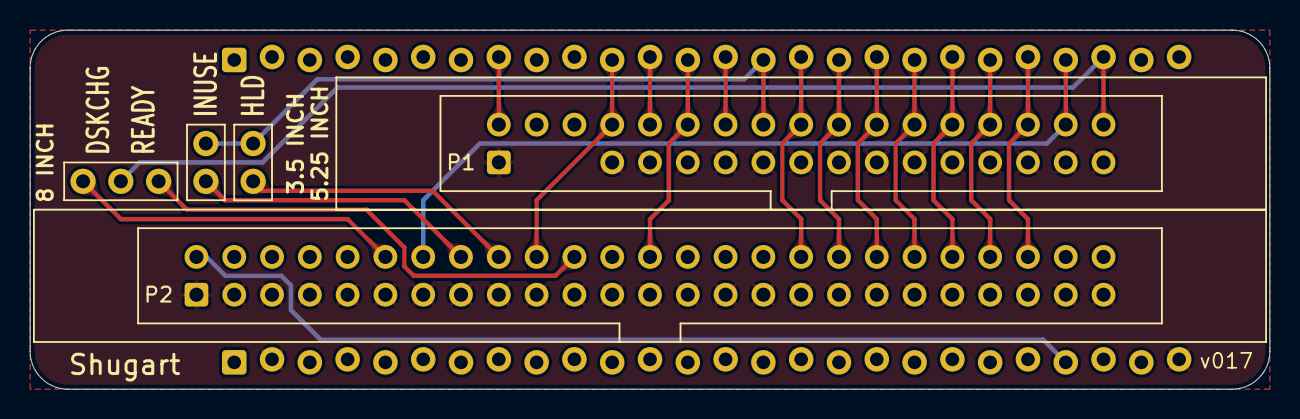
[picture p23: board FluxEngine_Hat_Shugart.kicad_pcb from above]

Board: 2 copper layers, 83.3 x 24.1 mm, 6 parts (1 on the bottom side), 21 nets.

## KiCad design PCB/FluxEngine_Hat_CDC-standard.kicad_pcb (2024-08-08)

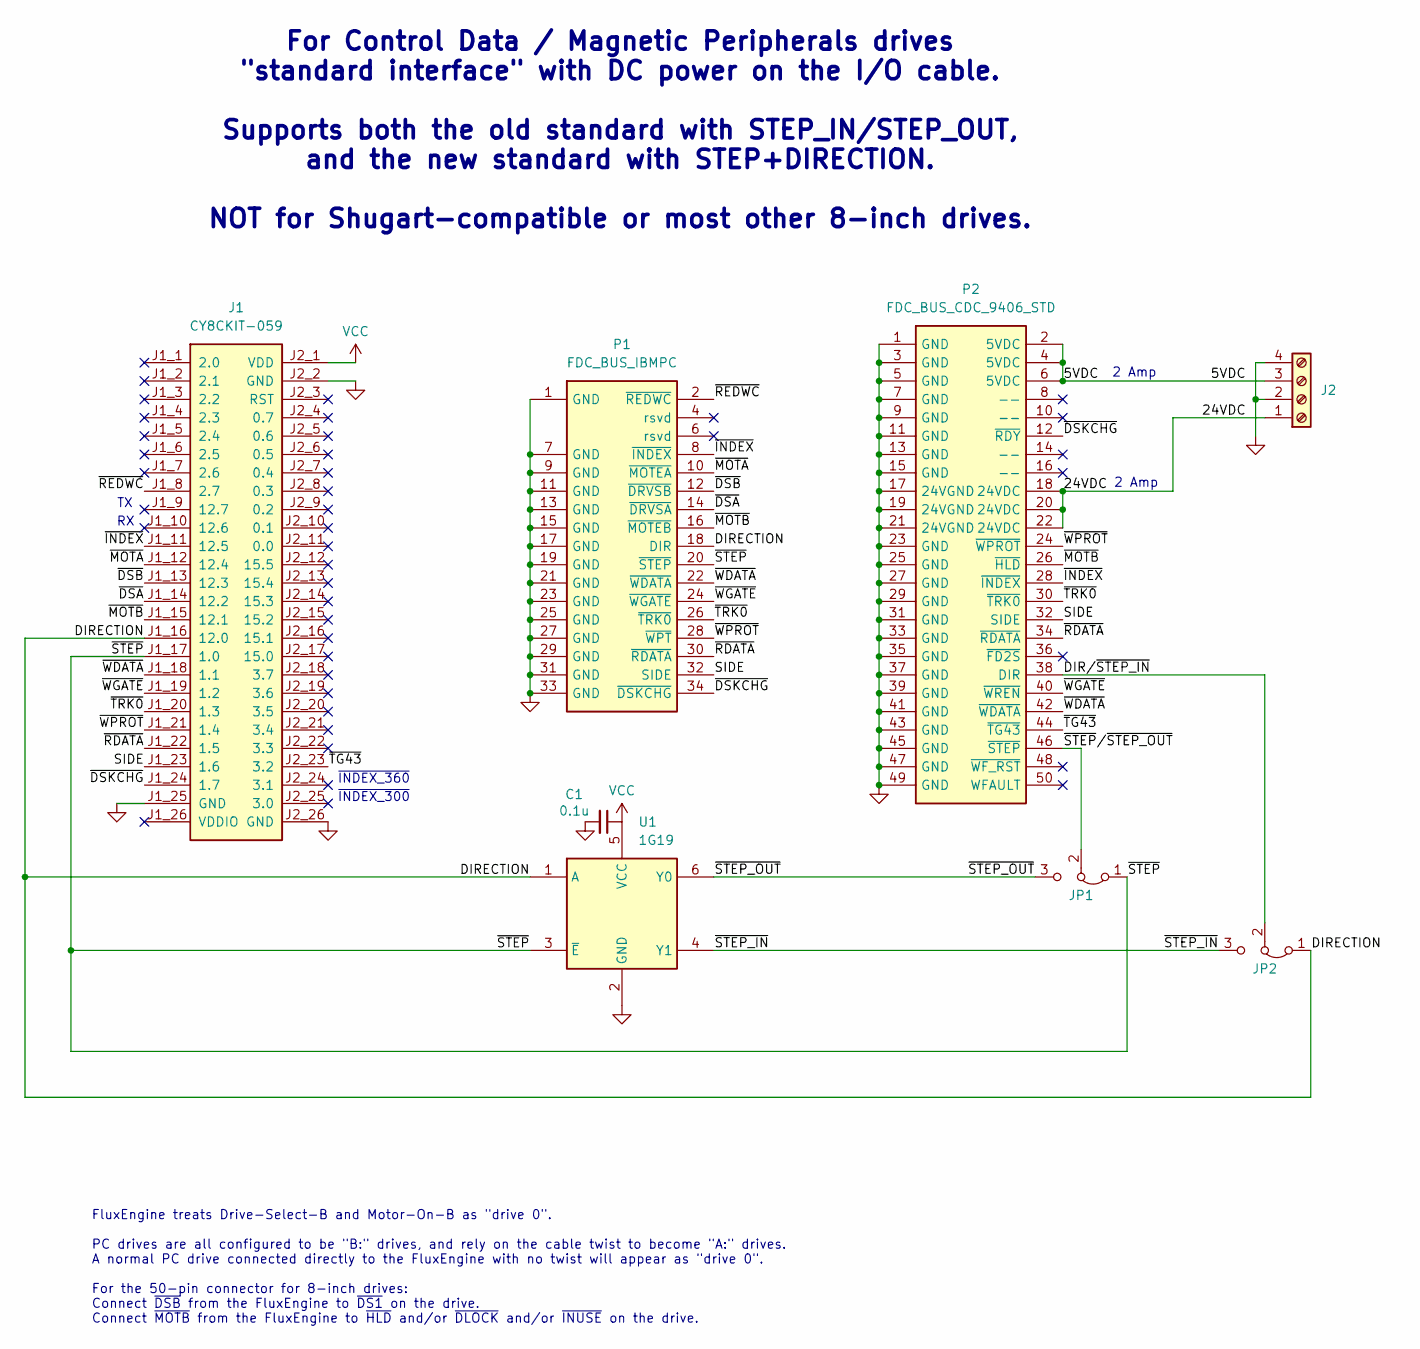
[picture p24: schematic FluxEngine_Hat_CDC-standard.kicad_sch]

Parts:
C1: 0.1u; C_0805_2012Metric
J1: CY8CKIT-059; CY8CKIT-059 dry fit
J2: Screw_Terminal_01x04; ScrewTerminal_1x04_P3.5mm_vertical
JP1, JP2: Jumper_3_Bridged12; PinHeader_1x03_P2.54mm_Vertical
P1: FDC_BUS_IBMPC; IDC-Header_2x17_P2.54mm_Latch_Vertical - FDD
P2: FDC_BUS_CDC_9406_STD; IDC-Header_2x25_P2.54mm_Latch_Vertical
U1: 1G19; SOT-363_SC-70-6

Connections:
/5VDC: J2.3, P2.2 (5VDC), P2.4 (5VDC), P2.6 (5VDC)
/24VDC: J2.1, P2.18 (24VDC), P2.20 (24VDC), P2.22 (24VDC)
/DIRECTION: J1.J1_16 (12.0), JP2.1 (A), P1.18 (DIR), U1.1 (A)
/DIR/~STEP_IN: JP2.2 (C), P2.38 (DIR)
/SIDE: J1.J1_23 (1.6), P1.32 (SIDE), P2.32 (SIDE)
/~DSA: J1.J1_14 (12.2), P1.14 (~DRVSA)
/~DSB: J1.J1_13 (12.3), P1.12 (~DRVSB)
/~DSKCHG: J1.J1_24 (1.7), P1.34 (~DSKCHG), P2.12 (~RDY)
/~INDEX: J1.J1_11 (12.5), P1.8 (~INDEX), P2.28 (~INDEX)
/~MOTA: J1.J1_12 (12.4), P1.10 (~MOTEA)
/~MOTB: J1.J1_15 (12.1), P1.16 (~MOTEB), P2.26 (~HLD)
/~RDATA: J1.J1_22 (1.5), P1.30 (~RDATA), P2.34 (~RDATA)
/~REDWC: J1.J1_8 (2.7), P1.2 (~REDWC)
/~STEP_IN: JP2.3 (B), U1.4 (Y1)
/~STEP_OUT: JP1.3 (B), U1.6 (Y0)
/~STEP: J1.J1_17 (1.0), JP1.1 (A), P1.20 (~STEP), U1.3 (~E)
/~STEP/~STEP_OUT: JP1.2 (C), P2.46 (~STEP)
/~TG43: J1.J2_23 (3.2), P2.44 (~TG43)
/~TRK0: J1.J1_20 (1.3), P1.26 (~TRK0), P2.30 (~TRK0)
/~WDATA: J1.J1_18 (1.1), P1.22 (~WDATA), P2.42 (~WDATA)
/~WGATE: J1.J1_19 (1.2), P1.24 (~WGATE), P2.40 (~WREN)
/~WPROT: J1.J1_21 (1.4), P1.28 (~WPT), P2.24 (~WPROT)
GND: C1.2, J1.J1_25 (GND), J1.J2_2 (GND), J1.J2_26 (GND), J2.2, J2.4, P1.1 (GND), P1.7 (GND), P1.9 (GND), P1.11 (GND), P1.13 (GND), P1.15 (GND), P1.17 (GND), P1.19 (GND), P1.21 (GND), P1.23 (GND), P1.25 (GND), P1.27 (GND), P1.29 (GND), P1.31 (GND), P1.33 (GND), P2.1 (GND), P2.3 (GND), P2.5 (GND), P2.7 (GND), P2.9 (GND), P2.11 (GND), P2.13 (GND), P2.15 (GND), P2.17 (24VGND), P2.19 (24VGND), P2.21 (24VGND), P2.23 (GND), P2.25 (GND), P2.27 (GND), P2.29 (GND), P2.31 (GND), P2.33 (GND), P2.35 (GND), P2.37 (GND), P2.39 (GND), P2.41 (GND), P2.43 (GND), P2.45 (GND), P2.47 (GND), P2.49 (GND), U1.2 (GND)
VCC: C1.1, J1.J2_1 (VDD), U1.5 (VCC)

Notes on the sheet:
FluxEngine treats Drive-Select-B and Motor-On-B as "drive 0". PC drives are all configured to be "B:" drives, and rely on the cable twist to become "A:" drives. A normal PC drive connected directly to the FluxEngine with no twist will appear as "drive 0". For the 50-pin connector for 8-inch drives: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
~{INDEX_300}
For Control Data / Magnetic Peripherals drives "standard interface" with DC power on the I/O cable. Supports both the old standard with STEP_IN/STEP_OUT, and the new standard with STEP+DIRECTION. NOT for Shugart-compatible or most other 8-inch drives.
2 Amp
~{INDEX_360}

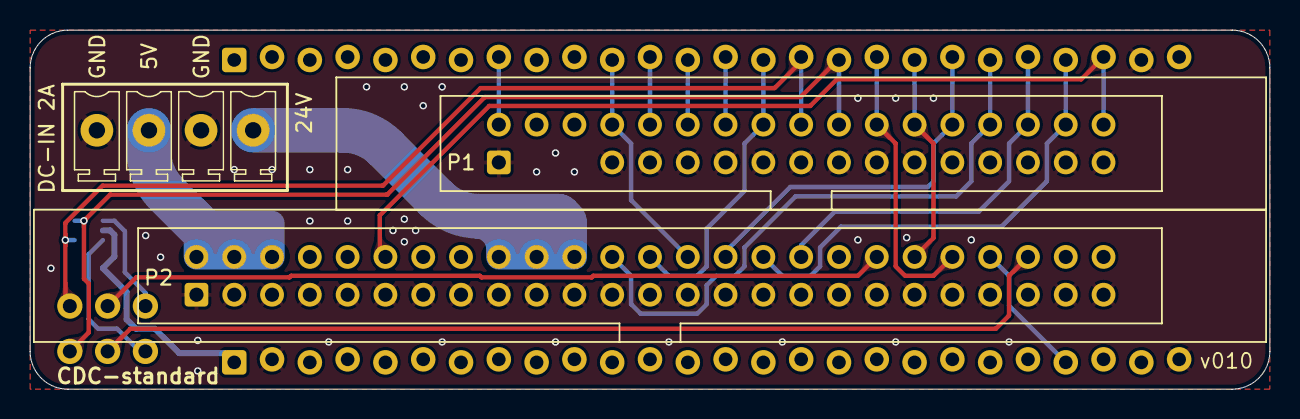
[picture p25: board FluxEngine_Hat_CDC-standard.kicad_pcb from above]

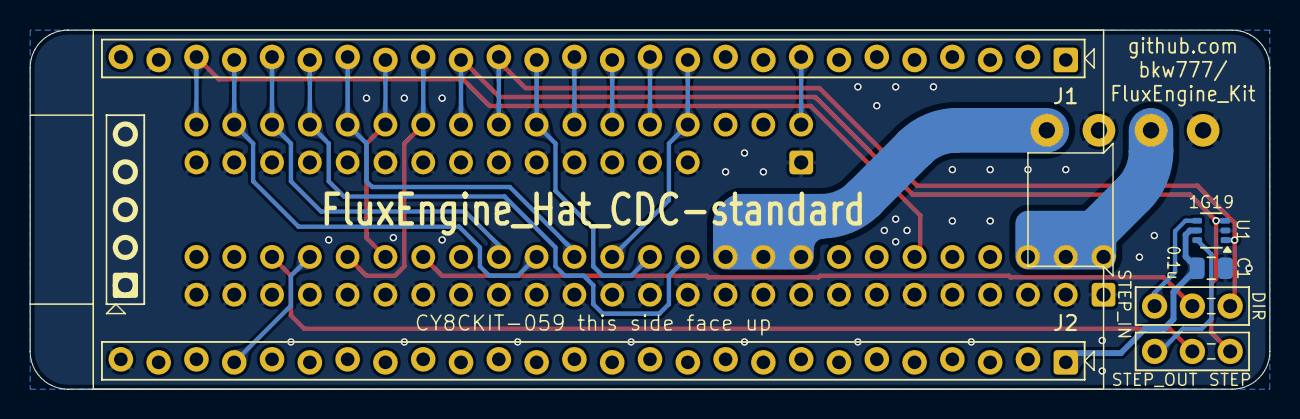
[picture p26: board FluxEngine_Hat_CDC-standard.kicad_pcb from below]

Board: 2 copper layers, 83.3 x 24.1 mm, 8 parts (5 on the bottom side), 24 nets.

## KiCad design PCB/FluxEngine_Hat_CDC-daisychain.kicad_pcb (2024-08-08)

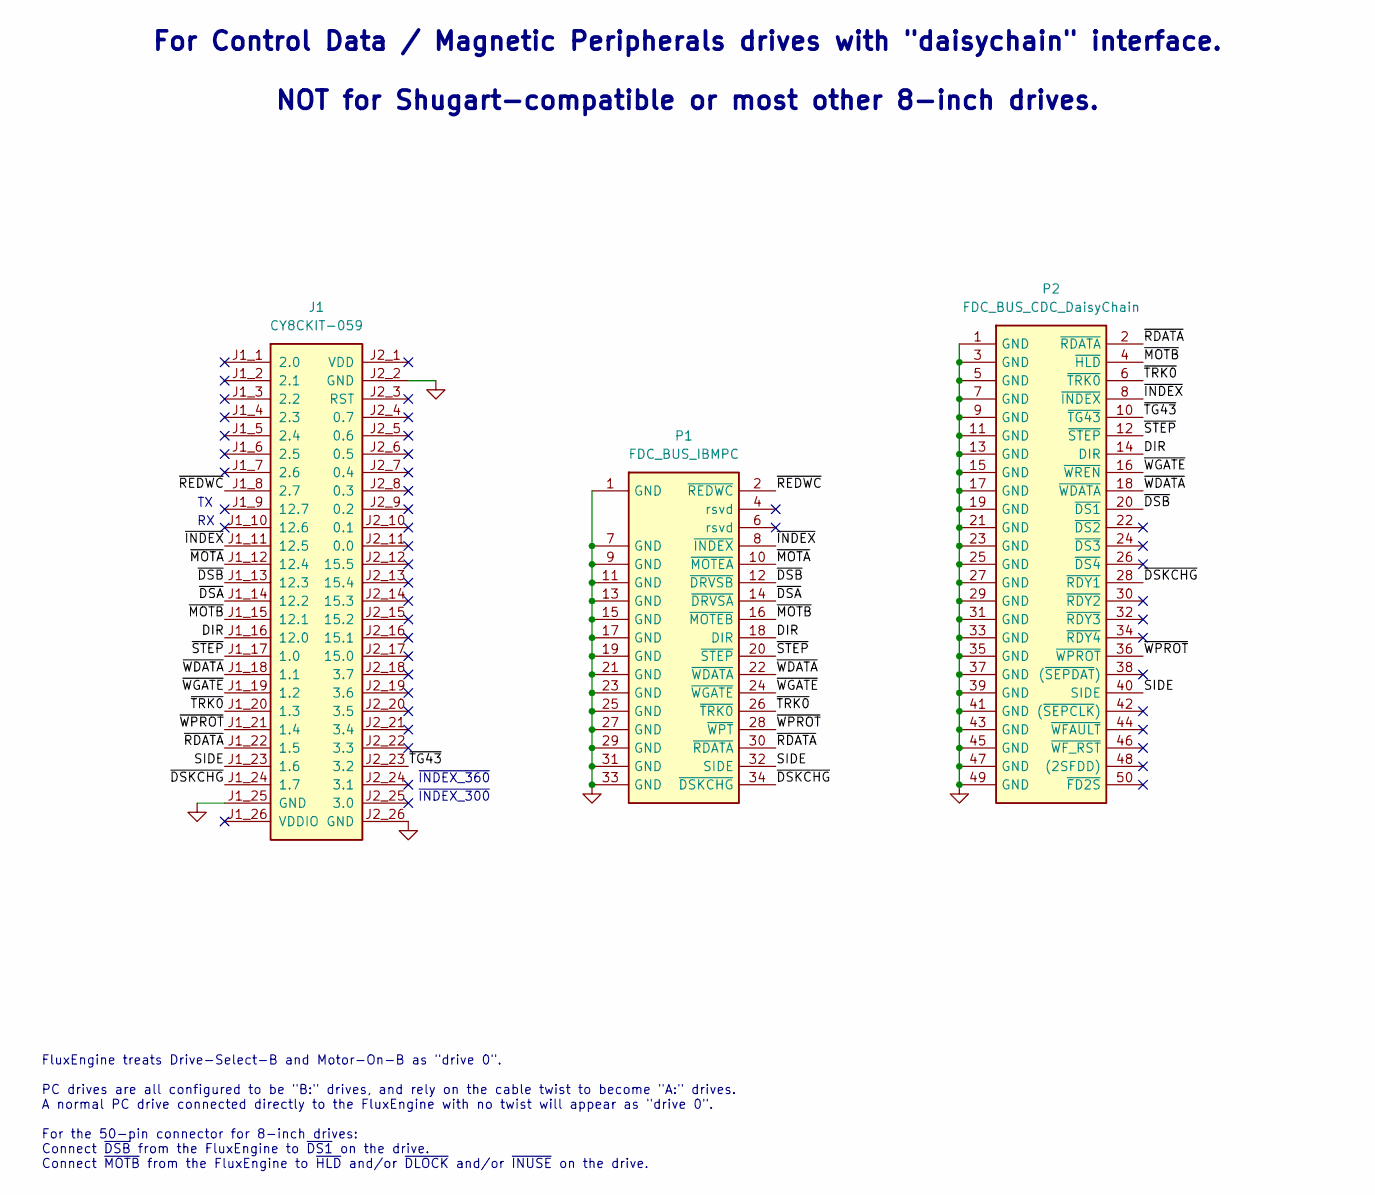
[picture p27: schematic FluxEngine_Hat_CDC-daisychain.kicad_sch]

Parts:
J1: CY8CKIT-059; CY8CKIT-059 dry fit
P1: FDC_BUS_IBMPC; IDC-Header_2x17_P2.54mm_Latch_Vertical - FDD
P2: FDC_BUS_CDC_DaisyChain; IDC-Header_2x25_P2.54mm_Latch_Vertical

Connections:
/DIR: J1.J1_16 (12.0), P1.18 (DIR), P2.14 (DIR)
/SIDE: J1.J1_23 (1.6), P1.32 (SIDE), P2.40 (SIDE)
/~DSA: J1.J1_14 (12.2), P1.14 (~DRVSA)
/~DSB: J1.J1_13 (12.3), P1.12 (~DRVSB), P2.20 (~DS1)
/~DSKCHG: J1.J1_24 (1.7), P1.34 (~DSKCHG), P2.28 (~RDY1)
/~INDEX: J1.J1_11 (12.5), P1.8 (~INDEX), P2.8 (~INDEX)
/~MOTA: J1.J1_12 (12.4), P1.10 (~MOTEA)
/~MOTB: J1.J1_15 (12.1), P1.16 (~MOTEB), P2.4 (~HLD)
/~RDATA: J1.J1_22 (1.5), P1.30 (~RDATA), P2.2 (~RDATA)
/~REDWC: J1.J1_8 (2.7), P1.2 (~REDWC)
/~STEP: J1.J1_17 (1.0), P1.20 (~STEP), P2.12 (~STEP)
/~TG43: J1.J2_23 (3.2), P2.10 (~TG43)
/~TRK0: J1.J1_20 (1.3), P1.26 (~TRK0), P2.6 (~TRK0)
/~WDATA: J1.J1_18 (1.1), P1.22 (~WDATA), P2.18 (~WDATA)
/~WGATE: J1.J1_19 (1.2), P1.24 (~WGATE), P2.16 (~WREN)
/~WPROT: J1.J1_21 (1.4), P1.28 (~WPT), P2.36 (~WPROT)
GND: J1.J1_25 (GND), J1.J2_2 (GND), J1.J2_26 (GND), P1.1 (GND), P1.7 (GND), P1.9 (GND), P1.11 (GND), P1.13 (GND), P1.15 (GND), P1.17 (GND), P1.19 (GND), P1.21 (GND), P1.23 (GND), P1.25 (GND), P1.27 (GND), P1.29 (GND), P1.31 (GND), P1.33 (GND), P2.1 (GND), P2.3 (GND), P2.5 (GND), P2.7 (GND), P2.9 (GND), P2.11 (GND), P2.13 (GND), P2.15 (GND), P2.17 (GND), P2.19 (GND), P2.21 (GND), P2.23 (GND), P2.25 (GND), P2.27 (GND), P2.29 (GND), P2.31 (GND), P2.33 (GND), P2.35 (GND), P2.37 (GND), P2.39 (GND), P2.41 (GND), P2.43 (GND), P2.45 (GND), P2.47 (GND), P2.49 (GND)

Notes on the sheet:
~{INDEX_300}
~{INDEX_360}
For Control Data / Magnetic Peripherals drives with "daisychain" interface. NOT for Shugart-compatible or most other 8-inch drives.
FluxEngine treats Drive-Select-B and Motor-On-B as "drive 0". PC drives are all configured to be "B:" drives, and rely on the cable twist to become "A:" drives. A normal PC drive connected directly to the FluxEngine with no twist will appear as "drive 0". For the 50-pin connector for 8-inch drives: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

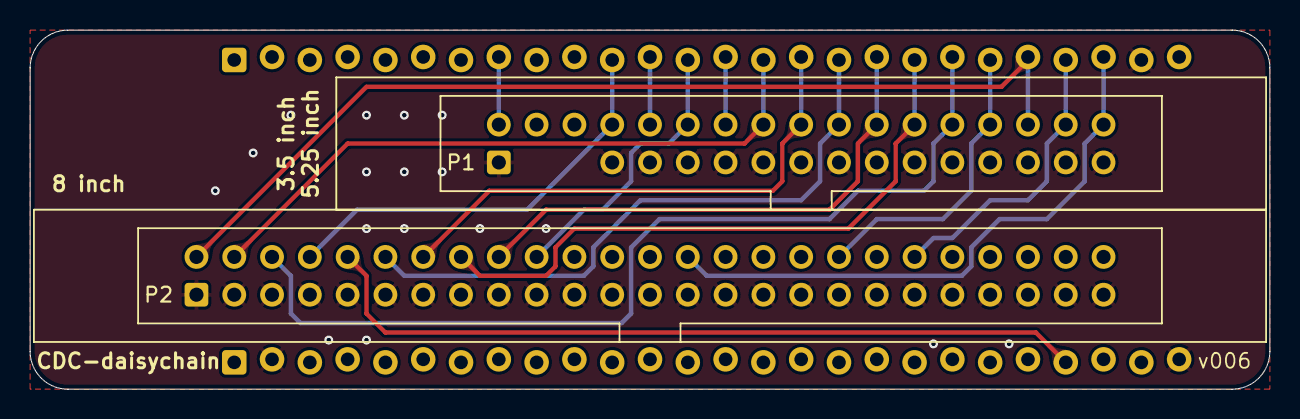
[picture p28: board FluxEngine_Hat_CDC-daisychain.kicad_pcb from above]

Board: 2 copper layers, 83.3 x 24.1 mm, 3 parts (1 on the bottom side), 17 nets.

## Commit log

2024-04-10 fdd symbols, rename to _Hat
    [FluxEngine_Hat.kicad_pcb, FluxEngine_Hat.kicad_sch, FluxEngine_IO.kicad_pcb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]
2024-04-13 v003 flip fpga board over
    [FluxEngine_Hat.kicad_pcb, FluxEngine_Hat.kicad_sch, FluxEngine_Hat_B.kicad_pcb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]
2024-04-16 jumper options and printable case
    [FluxEngine.stl, FluxEngine_Case.scad, FluxEngine_Case.stl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]
2024-04-17 snap cover, better 3d model files
    [FluxEngine.stl, FluxEngine_Case.scad, FluxEngine_Case.stl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]
2024-04-17 clean up unused symbols, footprints, models
2024-04-19 refactor cover, add slim cover variant
    [FluxEngine_Case.scad, FluxEngine_Case.stl, FluxEngine_Case_slim.stl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]
2024-04-20 fix posts in cover not touching outer wall
    [FluxEngine_Case.scad, FluxEngine_Case.stl, FluxEngine_Case_slim.stl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]
2024-04-20 slight adjustments to the cover
    [FluxEngine_Case.scad, FluxEngine_Case.stl, FluxEngine_Case_slim.stl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]
2024-04-21 better jumper arrangement, fix some signal names
    [FluxEngine_Case.scad, FluxEngine_Hat.kicad_pcb, FluxEngine_Hat.kicad_sch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]
2024-04-21 silkscreen & pics
    [FluxEngine_Hat.kicad_pcb]
2024-04-22 add FluxEngine_SlipCover.FCStd
    [FluxEngine_Case.scad, FluxEngine_Hat.kicad_pcb, FluxEngine_PCB.stl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]
2024-04-23 solderless pins footprint, add simple cover for solderless and sockets
    [FluxEngine_Hat.kicad_pcb, FluxEngine_Hat.kicad_sch, FluxEngine_SimpleCover.stl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]
2024-04-25 add CDC9406 type 1 & 2
    [FluxEngine_Hat.kicad_pcb, FluxEngine_Hat_CDC_9406_cfg_1.kicad_pcb, FluxEngine_Hat_CDC_9406_cfg_1.kicad_sch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]
2024-04-25 CDC pinouts
    [8-inch-FDD-pinouts.ods, FluxEngine_Hat.kicad_pcb, FluxEngine_Hat.kicad_sch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]
2024-04-25 readme & remove slash from page names
    [FluxEngine_Hat.kicad_pcb, FluxEngine_Hat_CDC.kicad_pcb, FluxEngine_Hat_CDC.kicad_sch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]
2024-04-27 cdc convert step
    [FluxEngine_Hat_CDC_ALT1_with_step_convert.kicad_pcb, FluxEngine_Hat_CDC_ALT1_with_step_convert.kicad_sch]
2024-04-27 WIP add step convert
    [FluxEngine_Hat_CDC_ALT1_with_step_convert.kicad_pcb, FluxEngine_Hat_CDC_ALT1_with_step_convert.kicad_sch]
2024-04-30 more CDC work
    [FluxEngine_Hat_CDC_9406_STD.kicad_pcb, FluxEngine_Hat_CDC_9406_STD.kicad_sch, FluxEngine_Hat_CDC_ALT1.kicad_pcb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]
2024-04-30 Combined CDC new & old standard interface
    [FluxEngine_Hat_CDC-daisychain.kicad_pcb, FluxEngine_Hat_CDC-daisychain.kicad_sch, FluxEngine_Hat_CDC-standard.kicad_pcb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]
2024-05-02 rename some of the printable covers
    [FluxEngine_FancyCover.lp.stl, FluxEngine_Hat_CDC-standard.kicad_pcb, FluxEngine_SimpleCover.lp.stl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]
2024-05-02 all covers from openscad
    [FluxEngine_Cover.scad, FluxEngine_FancyCover.lowprofile.stl, FluxEngine_FancyCover.lp.stl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]
2024-05-02 remove stl outputs from repo
    [FluxEngine_FancyCover.lowprofile.stl, FluxEngine_FancyCover.sockets.stl, FluxEngine_FancyCover.stl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]
2024-05-03 cover scad refactor some
    [FluxEngine_Cover.scad]
2024-05-03 increase fitment clearance in simple cover
    [FluxEngine_Cover.scad]
2024-05-04 schematic notes
    [FluxEngine_Hat.kicad_sch]
2024-05-06 silkscreen, pics
    [FluxEngine_Hat.kicad_pcb, FluxEngine_Hat_CDC-daisychain.kicad_pcb, FluxEngine_Hat_CDC-standard.kicad_pcb]
2024-05-11 fix CDC-standard backwards step_in/step_out decoding
    [8-inch-FDD-pinouts.ods, FluxEngine_Hat_CDC-standard.kicad_pcb, FluxEngine_Hat_CDC-standard.kicad_sch]
2024-05-11 CDC-standard silkscreen
    [FluxEngine_Hat_CDC-standard.kicad_pcb]
2024-05-11 CDC-standard adjust a trace
    [FluxEngine_Hat_CDC-standard.kicad_pcb]
2024-05-25 reduce thermal spoke width
    [8-inch-FDD-pinouts.ods, FluxEngine_Hat.kicad_pcb, FluxEngine_Hat_CDC-daisychain.kicad_pcb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]
2024-05-28 rotate 1G19 for easier hand soldering
    [FluxEngine_Hat.kicad_pcb, FluxEngine_Hat.kicad_sch, FluxEngine_Hat_CDC-standard.kicad_pcb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]
2024-06-06 CDC-standard traces to U1
    [FluxEngine_Hat_CDC-standard.kicad_pcb]
2024-08-08 staggered rows offset & direction
    [FluxEngine_Hat.kicad_pcb, FluxEngine_Hat_CDC-daisychain.kicad_pcb, FluxEngine_Hat_CDC-daisychain.kicad_sch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]
2024-08-08 shugart silkscreen
    [FluxEngine_Hat_Shugart.kicad_pcb]

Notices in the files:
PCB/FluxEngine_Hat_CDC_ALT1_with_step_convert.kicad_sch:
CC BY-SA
